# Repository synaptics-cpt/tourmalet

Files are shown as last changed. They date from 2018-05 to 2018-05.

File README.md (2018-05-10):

Synaptics Concept Prototyping Team 

&copy; 2018 Synaptics, Incorporated. All Rights Reserved

# Project Tourmalet - A Portable Multimedia player and Android Design Kit #
last update: May 10, 2018

Contact [Synaptics](mailto:tourmalet@synaptics.com)

The files in this repository, except where otherwise noted, are licensed under the Apache License, Version 2.0 (the "License"); you may not use these files except in compliance with the License. You may obtain a copy of the License at http://www.apache.org/licenses/LICENSE-2.0

*Legal Disclaimer: The information contained in this repository ("Tourmalet") is provided "as is," and Synaptics makes no warranties, express, implied, statutory, or otherwise, regarding Tourmalet or any related documentation.  Synaptics disclaims all liability of any kind in connection with Tourmalet and related documentation and specifically disclaims any implied warranties of noninfringement, title, merchantability, or fitness for a particular purpose, or arising from a course of dealing or usage of trade.* 

----------

Welcome to the Project Tourmalet Repository.  This should be the first document that you read about this project.  Here, you will find a high level description of the purpose, intent and vision of this project.  You will also find a roadmap of the other files and documents that are included in this repository.  

TL;DR: READ THIS DOCUMENT FIRST.  It will save you time.

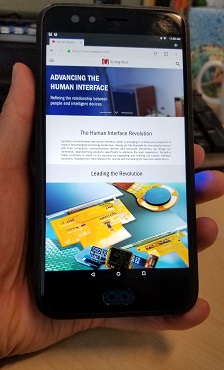
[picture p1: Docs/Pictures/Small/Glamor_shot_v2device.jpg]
Glamour Photo of Tourmalet Device Glamor photo of Tourmalet


## What is Project Tourmalet?  Why? ##

- A build kit for a handheld device and touchscreen development kit
	- Out-of-the-box experience (well, once assembled) as a handheld Android device – impress your friends with a hand-built Android device that can serve as a wireless communicator, music player, social media portal, etc.
	- Usable as a touchscreen development kit to enable touchscreen UI and GPIO access for other projects
- For the recreational hobbyist, a kit to build an Android handheld!
	- Build-it-yourself, battery operated handheld device kit with step-by-step instructions.  HW and SW binary image fully tested to work (so long as you follow our instructions).
	- Fully working high-end media player: FHD touchscreen, USB ports, rechargeable battery, WiFi and Bluetooth. FHD display comparable to any commercially available media player or low-end cell phone.
	- Runs Android OS, can install Amazon AppStore and run apps like Facebook, YouTube, FireFox. Infinitely customizable/personalizeable as HW and SW is "open sourced".
- For the advanced hobbyist, an extensible HD touchscreen development kit
	- Synaptics TDDI FHD touchscreen display easily outperforms other touchscreens currently available to hobbyists.
	- "Simplify" hobbyist touch-screen design-in experience for projects requiring touchscreen
		- Pre-defined touchscreen with HD display, sample source, GUI builder SW
		- NO SENSOR TUNING.  Touchscreen reports multi-finger touch "out-of-the-box" 
	- "...better than ripping apart a production handset just to get to the touchscreen"
		- I/O ports accessible to wire-in additional HW
		- Entire device documentation available (HW schematics, board files, casing design, SW source, etc.)

Project Tourmalet started as an internal Synaptics project to help our engineers learn more about the Synaptics Touch-Display Driver Integration (TDDI) technology.  This pioneering technology enables high-performance in-cell touchscreen display technology by co-locating the capacitive touch sensing circuits directly in the same silicon as the display driver circuits.  

As a service to the Maker community, Synaptics has now made this advanced display technology available on a widely available, hobbyist platform (the Qualcomm Dragonboard 410c).  Furthermore, because we ourselves like to make usable platforms, we have released all the instructions and documentation to enable the Maker community to build a complete stand-alone Android device using the Synaptics TDDI FHD touchscreen. 

The original intent for the Tourmalet kit was to create a design kit that was straightforward enough that even a recreational hobbyist could assemble it him/herself, just like putting together a Lego design or an Ikea furniture.  Accordingly, emphasis was placed on making the mechanical design and assembly simple and robust, at the slight penalty for sleekness and cost.  So yes, the overall design could have been optimized to make the device thinner, but that would have made assembling the device even more challenging.  Additionally, aside from the touchscreen display, we also wanted to make sure most of the components (such as the battery, processor platform, etc.) were easy to source.  We even tested the casing design to be printable using hobbyist-class FDM printers (not just the high-end objet printers).  

That said, we do recognize that the Synaptics-enabled TDDI touchscreen and the main daughterboard and adaptor board that connects the display to the Dragonboard are both not available on the open market.  Full documentation for these two boards are included (in the *Synaptics_Boards* directory) so you could make your own.  However, Synaptics intends on working with suppliers in the Maker community to make these displays and the support components available. Contact [Synaptics](mailto:tourmalet@synaptics.com?subject=Tourmalet%20availability%20request) for further information.  

## How do I get started? ##
Now that we've captured your interest in building your own Android device, the next step is to work through the rest of the collateral and documentation in this repository (in the *Docs* to build your own Tourmalet device. A quick tour (in approximate order of how you will build your device):

1. [The Bill of Materials](Docs/BOM.md). This document contains all the hardware components needed to assemble the device.  Links to where our team sourced the component are also provided.
2. [The Assembly Instructions](Docs/Assembly.md).  Once you have gathered all your components, here are the step-by-step instructions on how to assemble the device.
3. [Installing Android](Docs/InstallingAndroid.md). Once you have your device completely assembled, this document shows you how to install the software binary image onto your device.  In this repository, we have already included a working binary (assuming you used the same exact hardware we specified in the BOM), so you can just install this binary onto your device.  Otherwise, you can try your hand at building your own binary with our [Building Android](Docs/BuildingAndroid.md) guide (see below).
4. [User Guide](Docs/UserGuide.md). What to know about the device and how to use it. Includes a basic spec sheet for the device.
5. [Developer Guide](Docs/DeveloperGuide.md). How to access Tourmalet's hardware in Android apps (or from your PC).
6. *For Advanced Hobbyists only:* [Building Android](Docs/BuildingAndroid.md).  Read this if you are interested in compiling your own Android binary for Tourmalet.  For most hobbyists, you can just use the pre-built binary we have included in the repository.  Building a new binary is really only necessary if you want to see how an Android binary is built (the included scripts and patches are what we used to build the binary in the repository), or if you want to modify our scripts/patches because you want to modify our hardware.  
7. No project would be complete without an [Errata](Docs/Errata.md).  Sadly, not everything is working and there are some things that don't behave as ideally as they should.  Perhaps, you can think of this document as a suggestion list for future projects!

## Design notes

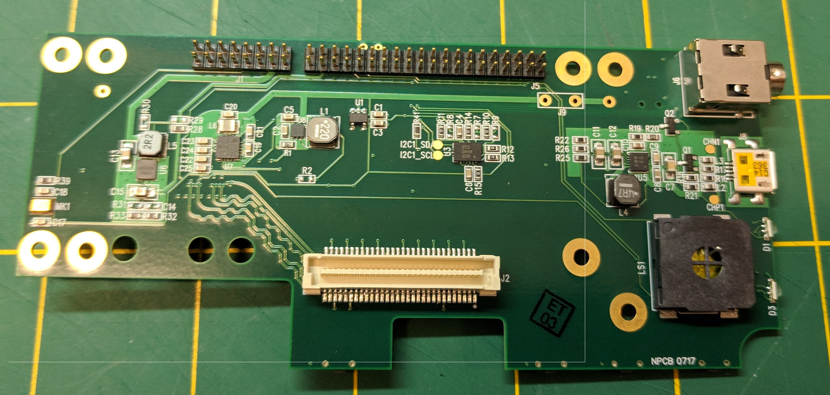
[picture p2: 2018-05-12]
Docs/Pictures/Full_size/daughter_board.jpg

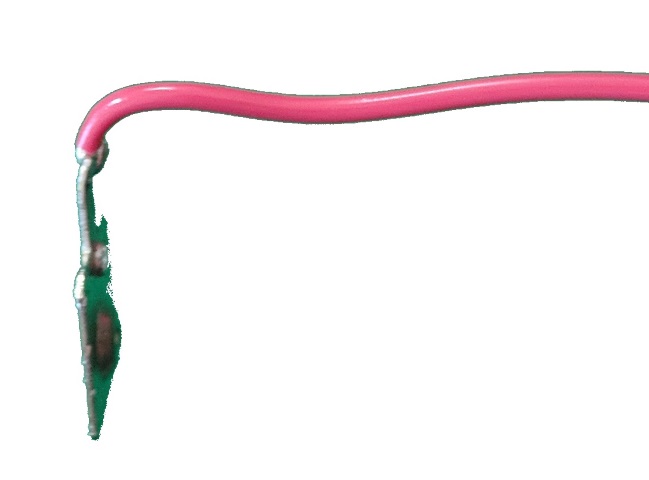
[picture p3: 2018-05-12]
Docs/Pictures/Small/wired_contact.jpg

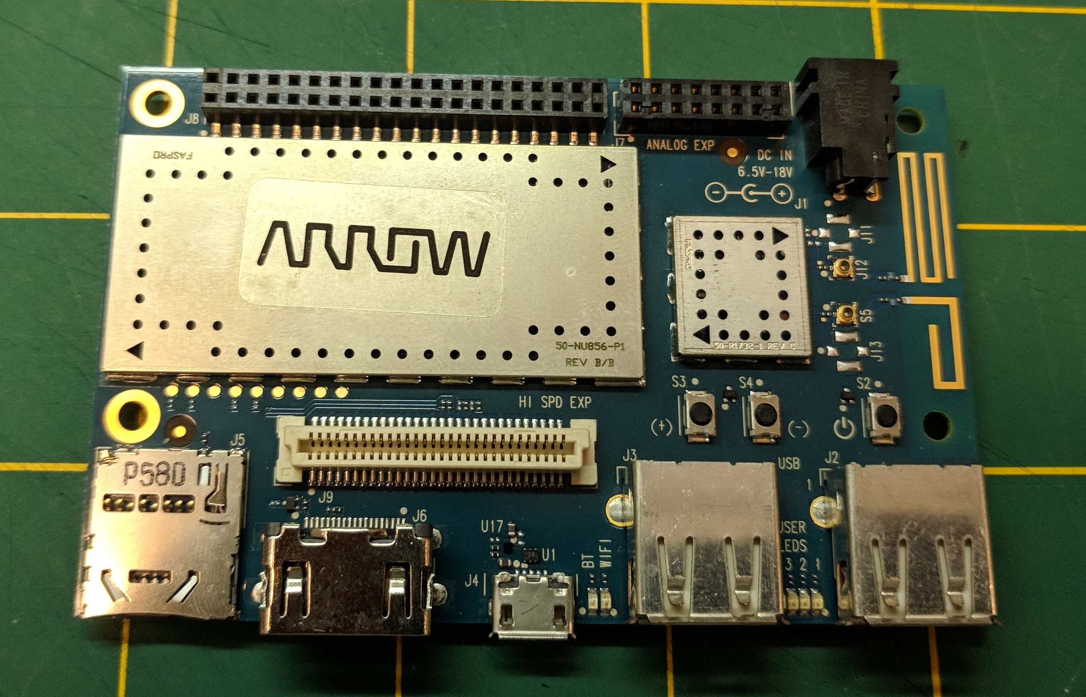
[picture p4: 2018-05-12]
Docs/Pictures/Full_size/dragonboard.jpg

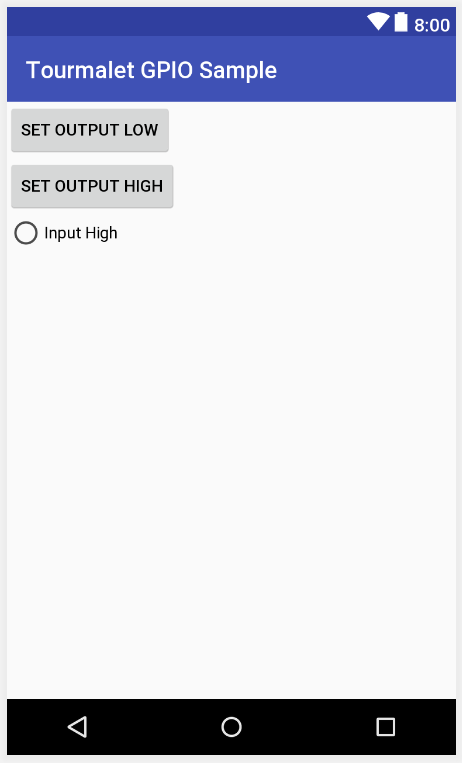
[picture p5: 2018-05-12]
Docs/Pictures/Full_size/Tourmalet_GPIO_Sample.png

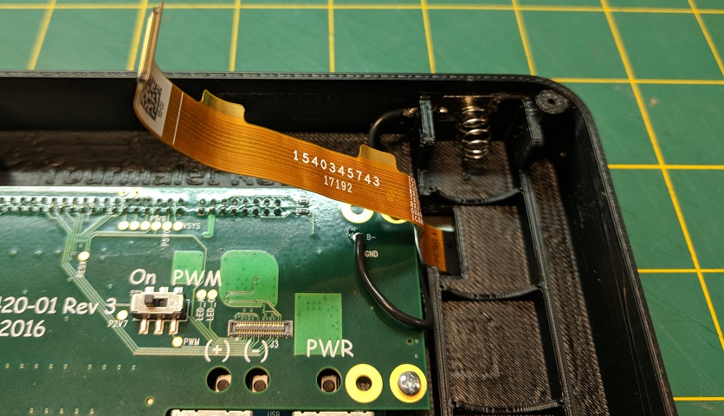
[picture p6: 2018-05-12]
Docs/Pictures/Small/negative_wire.jpg

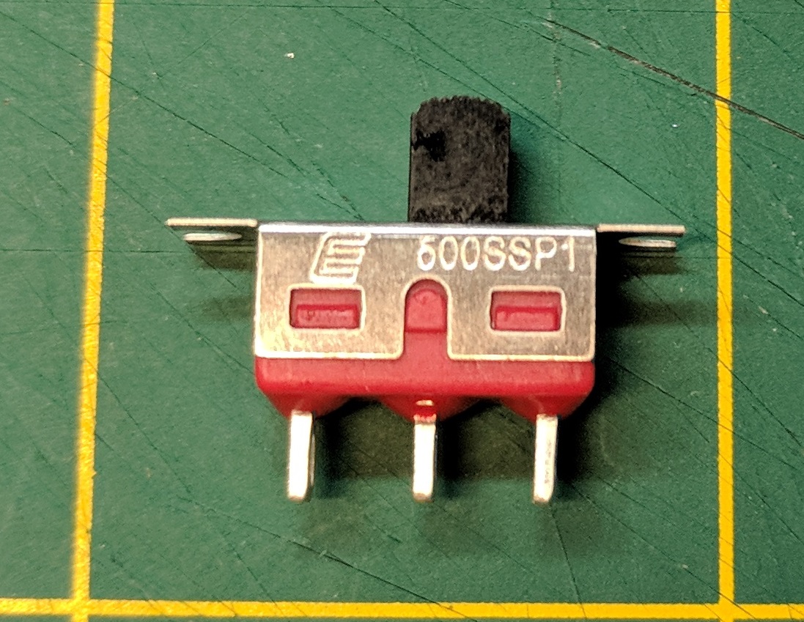
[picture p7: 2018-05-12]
Docs/Pictures/Full_size/switch.jpg

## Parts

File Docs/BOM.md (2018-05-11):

Synaptics Concept Prototyping Team 

&copy; 2018 Synaptics, Incorporated. All Rights Reserved
# Tourmalet Hardware Bill Of Materials

last update: May 10, 2018

Contact [Synaptics](mailto:tourmalet@synaptics.com)

This document tells you what all the parts are, where to get them, and what they look like.

## Parts list, and where to get them
| Item | Component (click link for source) | Quantity | Comments |
|---|---|---:|---|
| [3D Housing](#3d-printed-housing) | 3D case (Rev03a): [top](../Casing/Rev03a_shell_top.STL) and [bottom](../Casing/Rev03a_shell_bottom.STL)- or [one piece](../Casing/Rev03a_one_piece_shell.STL) | 1 | |
| [3D printed buttons](#3d-printed-buttons) | [3D printed buttons](../Casing/Rev03a_buttons.STL) | 1 | |
| [Processor platform](#dragonboard) | [Qualcomm Dragonboard 410c](https://www.arrow.com/en/products/dragonboard410c/arrow-development-tools) | 1 | May need to order from eBay |
| Daughterboard connector | 16-pin, 2 mm double row header, Digikey [609-2660-ND](https://www.digikey.com/product-detail/en/amphenol-fci/63453-116LF/609-2660-ND ) | 1 | |
| [Daughterboard](#daughter-board) | Synaptics internal part 950-000420-01 | 1 | Contact [Synaptics](mailto:tourmalet@synaptics.com) |
| [Battery contacts](#battery-contacts) | Negative: Digikey [36-5201-ND](https://www.digikey.com/product-detail/en/keystone-electronics/5201/36-5201-ND) | 1 | |
| | Positive: Digikey [36-5223-ND](https://www.digikey.com/product-detail/en/keystone-electronics/5223/36-5223-ND ) | 1 | |
| [Touchscreen](#touchscreen) | Tianma TL055VVMS15-00 (Synaptics TDDI) | 1 | Contact [Synaptics](mailto:tourmalet@synaptics.com) |
| [LCD Adaptor Board](#lcd-adaptor-board) | Synaptics internal part 950-000550-01 | 1 | Contact [Synaptics](mailto:tourmalet@synaptics.com) |
| [Power Switch](#power-switch) | SPDT switch: Digikey [EG2476-ND](https://www.digikey.com/product-detail/en/e-switch/EG2476-ND) | 1 | |
| [Battery](#battery) | [18650 Li-Ion battery](https://www.ebay.com/gds/18650-Battery-Buying-Guide-/10000000177628747/g.html) | 1 | Various sources; see ebay buying guide |
| [Themistor](#battery) | Digikey [490-8601-ND](https://www.digikey.com/product-detail/en/murata-electronics-north-america/NXRT15XH103FA1B030/490-8601-ND/3788625) | 1 | |
| Screws | M2 x 5 pan head | 12 | |
| | M2 x 3 flat head | 2 | |
| Misc. Wire | 22 or 24 gauge in various colors (red, black, etc.) | TBD | |
| [Pressure Sensitive Adhesive](#pressure-sensitive-adhesive) | 3M VHB 5909, 486MP, or similar | TBD | |

## Further explanation of the parts

### 3D Printed Housing
Part files are available as two pieces- [top](../Casing/Rev03a_shell_top.STL) and [bottom](../Casing/Rev03a_shell_bottom.STL)- or [one](../Casing/Rev03a_one_piece_shell.STL). The one-piece housing may be more difficult to print correctly and only saves 1mm in height.

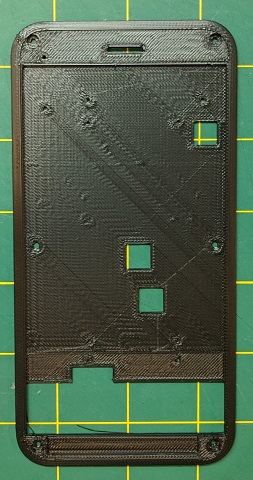
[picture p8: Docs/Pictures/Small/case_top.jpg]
Case top Casing top
 
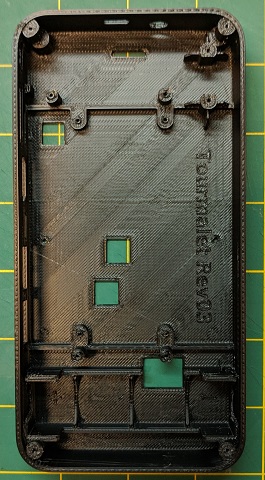
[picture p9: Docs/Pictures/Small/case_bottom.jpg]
Case bottom Casing bottom


### 3D Printed Buttons
Same [part](../Casing/Rev03a_buttons.STL) is used for both two-piece and single piece shell.

### DragonBoard
We are using the Dragonboard 410c.  This SBC is available from various online resellers. We got ours from [Arrow](https://www.arrow.com/en/products/dragonboard410c/arrow-development-tools), though you may need to check around as the 410c was released in 2016, so it's getting a bit old.
We will flash our build image after assembly, but make sure the DIP switches are all set to OFF.

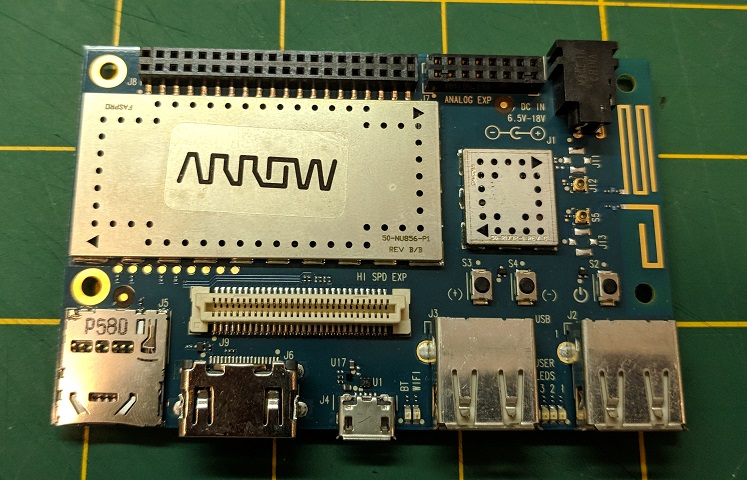
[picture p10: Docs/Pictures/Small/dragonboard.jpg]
Dragonboard Dragonboard 410c from Arrow


### Daughter Board
This Synaptics-design daughterboard (950-000420-01) contains a MIPI DSI connector (via an [adaptor board](#lcd-adaptor-board)), 3.3V display power, drive current for LED display backlight (and switch), speaker, battery charging, headphone jack, expansion connector, power for USB ports, and 9-axis sensor (magnetometer, accelerometer and gyroscope).  

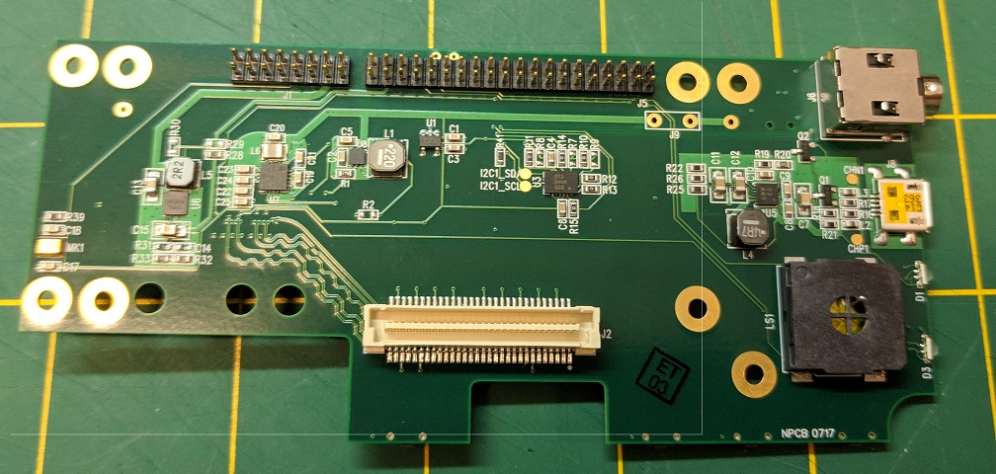
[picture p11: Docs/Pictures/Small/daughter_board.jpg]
daughter board Don't try building this by yourself!


All information needed to build this board (BOM, Schematic, PCB artwork) is contained in the *Synaptics_Boards* directory. However, we are assuming that you have an assembled daughterboard already, as the sourcing, PCB fab, assembly, and testing of this board is a rather advanced project in itself.  Contact [Synaptics](mailto:tourmalet@synaptics.com) for further information about sources for this board.

### Battery Contacts
Digikey part numbers available in the table above.

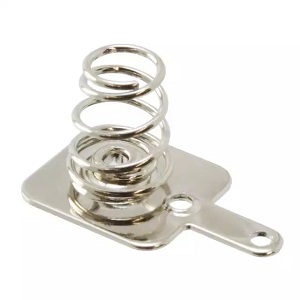
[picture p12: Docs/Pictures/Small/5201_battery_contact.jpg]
Negative battery contact
 
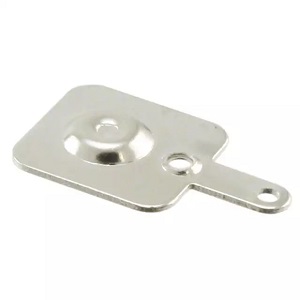
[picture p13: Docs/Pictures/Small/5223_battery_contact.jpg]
Positive battery contact


### Touchscreen
This is a Tianma TL055VVMS15-00 in-cell touchscreen display with an integrated cover lens.  It is a 5.46" FHD (1920 x 1080) touchscreen module, with integrated cover lens.  This touchscreen module features a Synaptics TD4322 touch-display driver integration (TDDI) chipset to provide high-performance in-cell capacitive multitouch.  Communication with the dragonboard is done via a MIPI DSI connection.  

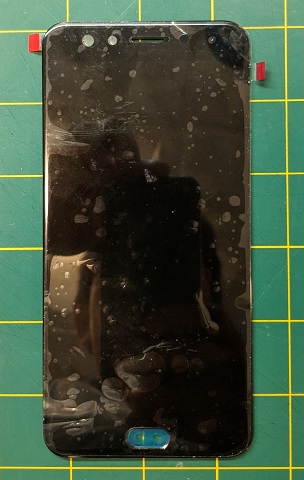
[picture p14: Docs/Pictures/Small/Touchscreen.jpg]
Touchscreen


In order to get the current version of Tourmalet to work with the supplied software binary image, it is critical that this exact touchscreen display be used.  No other display will work with this software binary, as the display configuration parameters in the binary are specifically tuned to this display. 

Contact [Synaptics](mailto:tourmalet@synaptics.com) for further information about sourcing this display.

### LCD Adaptor Board
Currently, the daughterboard (520-000420-01) with all the DragonBoard interface connectors (mezzanine connector, analog hconnector, and high speed digital signals) was designed for an LCD with a different pinout, even though it has the same connector as the Tianma LCD used in this case. This LCD adapter board (520-000550-01) is needed to work with the Tianma LCD. A future iteration of the daughterboard might correct the LCD pinout to eliminate this adapter board.  

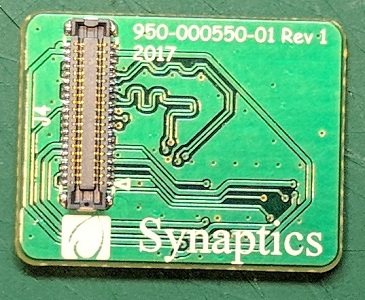
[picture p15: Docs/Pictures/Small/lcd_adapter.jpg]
LCD adapter board LCD adaptor board for daughterboard


All information about this board (BOM, schematic, PCB artwork) can be found in the *Synaptics_Boards* directory, though sourcing the connector may be an issue. Contact [Synaptics](mailto:tourmalet@synaptics.com) for further information about sources for this board.

### Power Switch
Power switch

Because we have not been successful at controlling the DragonBoard's PMIC, it is currently not possible to shut down the processor via software. Attempting to do so only works until the watchdog timer turns the Dragonboard back on again.  Accordingly, we have included a power switch, so you do not have to remove the battery whenever you want to turn off your Tourmalet device. Regular standby does work to shut off the LCD (and possibly put the processor in a lower power state?), but will still eventually drain the battery.
The power switch can be bypassed and not even used by putting a jumper (or zero ohm resistor) in part R40 on the daughter board.

### Battery
The battery used here is a relatively standard size rechargeable Lithium Ion cell. There is much more information available about these batteries than we can relay here, thus the link to a quick primer on eBay, above.

Due to the battery contacts, we recommend the use of button top (instead of flat top) batteries. We also recommend the use of protected cells for general safety. A protected 18650 battery is one that has a circuit on it to prevent electrical damage to the cell due to such factors as over charging, over discharging, short circuits, etc. 

Being a Lithium Ion battery, there are certain precautions one should follow when using it to reduce the risk of fire. We attempt to prevent charging problems by using a lithium ion specific charging ASIC, and we charge the battery at a moderate current. This means that the battery does not charge as fast as it could, but it also allows for different capacity batteries and also extends their service life.

We also provide contacts for the thermistor that the charging ASIC has provisions for. This thermistor is placed next to the battery so that charging circuit can reduce the charging current if the battery is getting too hot. Unfortunately, on the most recent board (as of April 2018), these contact are far from the actual battery itself, so the thermistor needs to have additional wires soldered to it so that it can properly be placed by the battery.

### Pressure Sensitive Adhesive
This adhesive needs to be able to stick well to both the smooth glass of the touchscreen, and the rough surface of the 3D printed case. The 3M VHB is often used for attaching glass to plastic. For FFF 3D printed materials, the adhesive should be at least 0.2mm thick. The VHB 5909 used here is 0.3mm. We have done no rigorous testing to determine the optimal adhseive - we simply had this particular adhesive available, and it seems to work well enough to keep the touchscreen attached to the plastic case.

If the surface texture of the plastic case is smooth - for example, if the case is made from a smooth photoresin, or the surface has been smoothed with filler such as epoxy or Bondo- then a 3M 200 series adhesive, such as 468MP, might be acceptable.

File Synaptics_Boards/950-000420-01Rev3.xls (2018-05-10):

SCH,DRAGONBOARD 410C TO DISPLAY ADAPTOR Revised: Thursday, April 26, 2018
SC950-000420-01 Revision: 3
Item | Quantity | Reference | Part | Decal | DigiKey
1 | 5 | C1,C5,C6,C9,C19 | 2.2uF | 0603 | 587-1430-1-ND
2 | 1 | C2 | 1.0uF | 0603 | 587-4958-1-ND
3 | 8 | C3,C4,C8,C16,C17,C18,C24,C25 | 0.1uF | 0603 | 490-6049-1-ND
4 | 2 | C7,C13 | 10uF | 0805 | 490-5523-1-ND
5 | 1 | C10 | 0.22uF | 0603 | 490-3290-1-ND
6 | 3 | C11,C12,C15 | 22uF | 0805 | 490-10511-1-ND
7 | 4 | C20,C21,C22,C23 | 4.7uF | 0603 | 587-3416-1-ND
8 | 2 | D1,D3 | 598-8510 | 598-8510 | 350-2072-1-ND
9 | 1 | D2 | BAT54C | SOT23 | BAT54C-FDICT-ND
10 | 1 | J1 | CON16A | 57102-xxx-08 | 609-2597-ND
11 | 1 | J2 | CON60 | 61083-06xx0x | 609-1677-1-ND
12 | 1 | J3 | CON40A | WP7B-S040VAX_ALT | 670-2806-1-ND
13 | 1 | J5 | CON40A | 57102-XXX-20 | 609-2589-ND
14 | 1 | J6 | SJ-435107RS | SJ-435107RS | CP-435107RS-ND
15 | 1 | J8 | uUSB | MOLEX47642-0001 | WM1398CT-ND
16 | 1 | LS1 | SPEAKER | SMS-1508 | 668-1260-1-ND
17 | 1 | L1 | 22uH | NRS5030 | 587-2411-1-ND
18 | 2 | L2,L3 | F-BEAD | 603 | 490-5222-1-ND
19 | 1 | L4 | 4.7uH | NRS5030 | 587-3461-1-ND
20 | 1 | L5 | 2.2uH | ASPI-0418FS | 535-10759-1-ND
21 | 1 | L6 | 4.7uH | 1008 | 490-10577-1-ND
22 | 1 | MK1 | SPA2410LR5H-B | SPA2410 | 423-1161-1-ND
23 | 4 | VOLUP,VOLDN,RST,PWR | SW SPST | EVQ9P701P | P19095CT-ND
24 | 4 | Q1,Q2,Q3,Q4 | 2N7002 | SOT23 | 2N7002K-7DICT-ND
25 | 1 | R1 | 5.1 | 0603 | P5.1GCT-ND
26 | 2 | R5,R39 | 2k | 0603 | P2.00KHCT-ND
27 | 3 | R6,R33,R34 | 105k | 0603 | P105KHCT-ND
28 | 6 | R10,R11,R12,R13,R14,R15 | 0 | 0603 | P0.0GCT-ND
29 | 5 | R16,R18,R22,R28,R41 | 47k | 0603 | P47.0KHCT-ND
30 | 1 | R17 | 470k | 0603 | P470KHCT-ND
31 | 1 | R19 | 27k | 0603 | P27.0KHCT-ND
32 | 1 | R20 | 22k | 0603 | P22.0KHCT-ND
33 | 1 | R21 | 100 | 0603 | P100HCT-ND
34 | 2 | R23,R38 | 270 | 0603 | P270HCT-ND
35 | 2 | R24,R37 | 330 | 0603 | P330HCT-ND
36 | 2 | R25,R36 | 12.4k | 0603 | P12.4KHCT-ND
37 | 1 | R26 | 53.6k | 0603 | P53.6KHCT-ND
38 | 1 | R27 | 10k@25°C | NXRT15 | 490-8601-ND
39 | 1 | R32 | 768k | 0603 | P768KHCT-ND
40 | 1 | R35 | 1.5k | 0603 | P1.50KHCT-ND
41 | 1 | SW1 | SW SPDT | JS202011SCQN | 401-2002-1-ND
42 | 1 | SW5 | SW DPDT | AYZ0202 | 401-2013-1-ND
43 | 1 | U1 | TC1014 | SOT23-5 | TC10142.7VCT713CT-ND
44 | 1 | U3 | BMX055 | BMX055 | 262-BMX055
45 | 1 | U4 | ADCMP670 | SOT23-6 | ADCMP670-1YUJZ-RL7CT-ND
46 | 1 | U5 | AAT3620 | TDFN14_040 | 863-1509-1-ND
47 | 1 | U6 | PAM2401_DFN | DFN12_045 | PAM2401YPADJDICT-ND
48 | 1 | U7 | BD83854MUV | QFN20_050 | BD83854MUV-E2CT-ND
49 | 1 | U8 | AL3050 | DFN6_065 | AL3050FDC-7DICT-ND

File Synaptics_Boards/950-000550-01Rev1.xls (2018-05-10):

SCH,Tourmalet Display adaptor Revised: Wednesday, September 06, 2017
SC950-000550-01 Revision: 1
Item | Quantity | Reference | Part | Decal | DigiKey
1 | 1 | J3 | 950-000420-01Rev1 | WP7B-P040VAX_SEQ_MIR | 670-2813-1-ND
2 | 1 | J4 | Display | AXE540xxx_ALT | 255-5433-ND

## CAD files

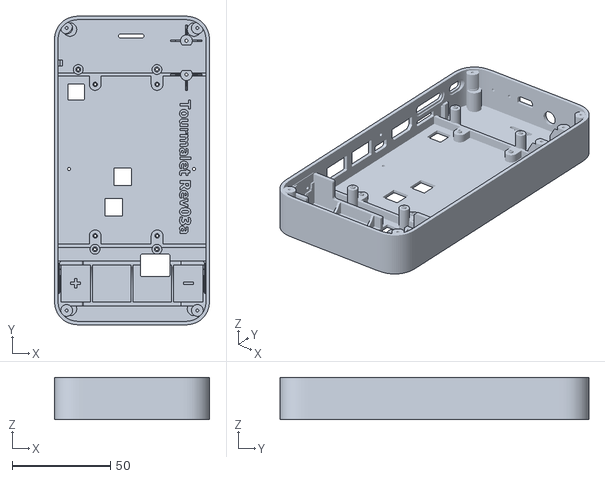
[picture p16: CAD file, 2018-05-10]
Casing/Rev03a_shell_bottom.STL
79.0 x 157.1 x 21.5

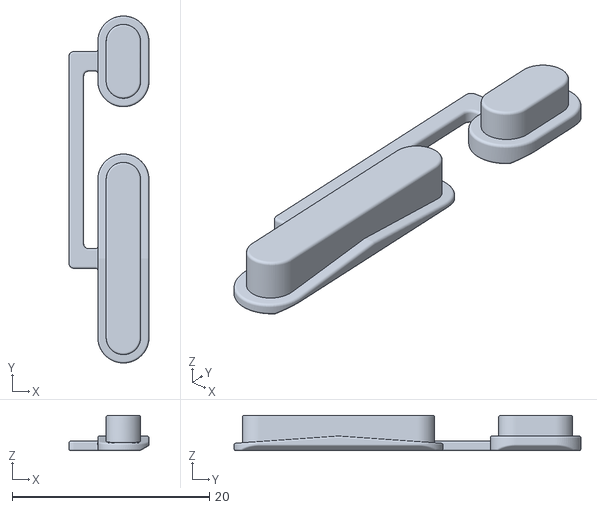
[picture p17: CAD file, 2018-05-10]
Casing/Rev03a_buttons.STL
8.12 x 35.2 x 3.60

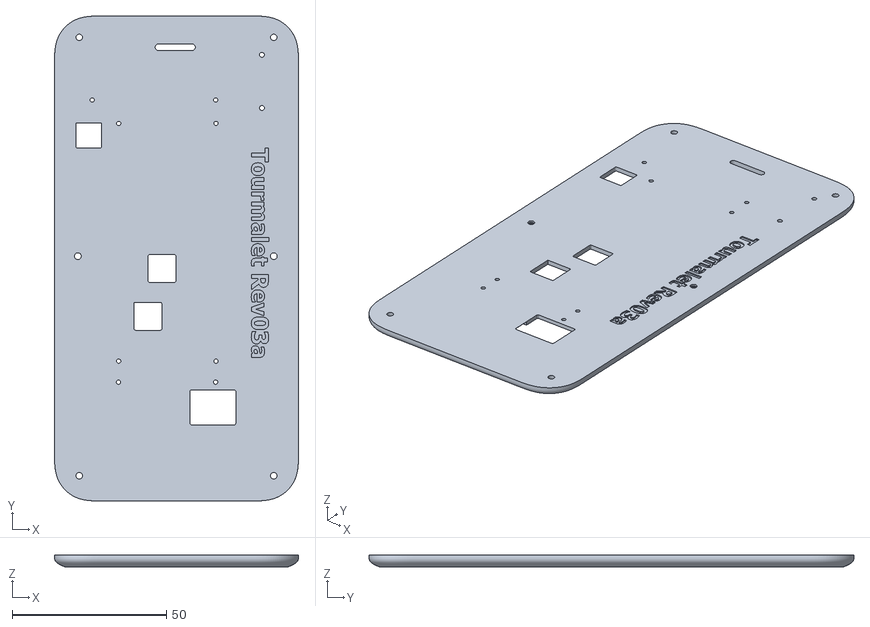
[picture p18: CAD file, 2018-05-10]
Casing/Rev03a_shell_top.STL
79.0 x 157.1 x 3.74

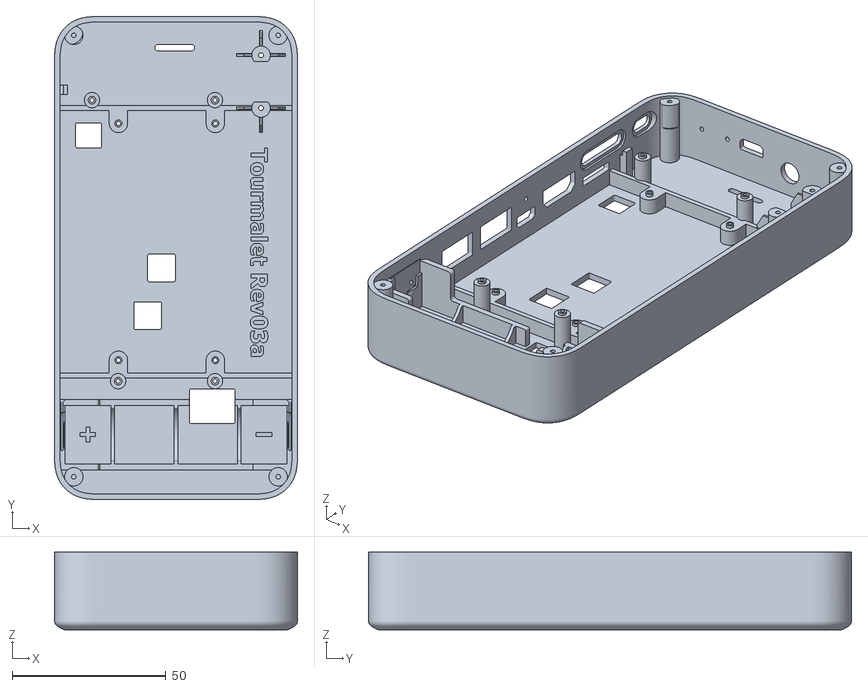
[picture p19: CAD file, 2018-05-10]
Casing/Rev03a_one_piece_shell.STL
79.0 x 157.1 x 25.2

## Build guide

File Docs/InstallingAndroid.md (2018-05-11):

Synaptics Concept Prototyping Team 

&copy; 2018 Synaptics, Incorporated. All Rights Reserved

# Installing Android on Tourmalet #

last update: May 10, 2018

Contact [Synaptics](mailto:tourmalet@synaptics.com)

- Install Android SDK from https://developer.android.com/studio/ or just the Platform Tools (smaller download/installation) from https://developer.android.com/studio/releases/platform-tools or, on Ubuntu Linux, fastboot as below:
```{r, engine=sh}
sudo add-apt-repository ppa:nilarimogard/webupd8
sudo apt-get update
sudo apt-get install android-tools-fastboot
```

- If you are using Ubuntu Linux, Install udev rules so that adb and fastboot will work without root permissions (or remember to use su or sudo to run adb and fastboot):

```{r, engine=sh}
git clone https://github.com/snowdream/51-android
sudo ln -s `pwd`/51-android/51-android.rules /etc/udev/rules.d/
sudo udevadm control --reload-rules
```
- Make sure the directory containing fastboot is in your `PATH` environment variable.

- Connect your Tourmalet device to your PC in fastboot mode:

	1. Unplug the device and make sure that the device is off
	2. Put in a charged battery (or plug device into charger via the top USB micro port).
	3. With a paperclip or other thin stick, press the *dragonboard's* volume down button (accessed via the middle hole in the daughterboard, located between the USB A ports) and then turn on power switch:

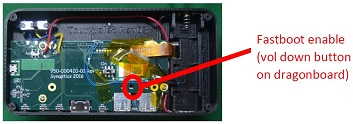
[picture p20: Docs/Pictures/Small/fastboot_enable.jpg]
fastboot_enable Push in this button to enable fastboot
	

	4. Once you switch on the power, you can let go of the button.  Now wait about 20 seconds and then plug the device into your PC via the side USB micro port.
	5. Check to make sure your device is recognized with the `fastboot devices -l` command.
	6. For additional help, you can also refer to the [96boards fastboot help page](https://www.96boards.org/documentation/consumer/dragonboard410c/installation/linux-fastboot.md.html), especially steps 1 and 2.

- Extract [fastboot-images.zip](https://github.com/synaptics-cpt/tourmalet/releases/download/v1.0.0/fastboot-images.zip) (`unzip fastboot-images.zip`).  

- On Windows, run `flash-all.bat`; on other platforms, `./flash-all.sh`.

- If you built your own image from source (using [Building Android](BuildingAndroid.md)), you will need to run these commands (that is, building your own "flash-all" script):

```{r, engine=sh}
for i in boot system userdata persist recovery; do fastboot flash $i APQ8016_420C_LA.BR.1.2.4-01810-8x16.0_5.1.1_Lollipop_P2/out/target/product/msm8916_64/$i.img; done
fastboot reboot
```

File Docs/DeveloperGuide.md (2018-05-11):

Synaptics Concept Prototyping Team 

&copy; 2018 Synaptics, Incorporated. All Rights Reserved

# Developer Guide #

last update, May 10, 2018

Contact [Synaptics](mailto:tourmalet@synaptics.com)

Writing Android apps to use Tourmalet hardware features such as GPIOs, UART, and buses requires some understanding of three layers: [Electical](#electrical) connections & pinout, [sysfs](#sysfs) interface for Linux hardware access, and using [libsuperuser](#libsuperuser) to get a privileged command shell from Android.

## Electrical ##

The DragonBoard 410c provides access to many I/O lines on the 40 pin low speed header. Some of these are used by the DragonBoard or Tourmalet expansion board and should generally not be used for further expansion, as this may cause hardware contention issues and unexpected behavior.

| Pin number | Signal name  | GPIO number | comment | | Pin number | Signal name  | GPIO number | comment |
| ---: | :---: | ---: | :--- | - | ---: | :---: | ---: | :--- |
| 1 | GND | | logic level low  | | 2 | GND | | |
| 3 | UART0_CTS | 904 | | | 4 | Power button | | |
| 5 | UART0_TX | 902 | | | 6 | Reset button | | |
| 7 | UART0_RX | 903 | | | 8 | SPI0_CLK | 921 | accelerometer |
| 9 | UART0_RTS | 905 | | | 10 | SPI0_MISO | 919 | accelerometer |
| 11 | UART1_TX | 906 | | | 12 | SPI0_CS_N | 920 | accelerometer |
| 13 | UART1_RX | 907 | | | 14 | SPI0_MOSI | 918 | accelerometer |
| 15 | I2C0_SCL | 909 | touch at 0x20 | | 16 | Reserved | | |
| 17 | I2C0_SDA | 908 | touch at 0x20 | | 18 | Reserved | | |
| 19 | I2C1_SCL | 925 | sensors | | 20 | Reserved | | |
| 21 | I2C1_SDA | 924 | sensors | | 22 | Reserved | | |
| 23 | GPIO_36 | 938 | 5V enable | | 24 | GPIO_12 | 914 | |
| 25 | GPIO_13 | 915 | touch ATTN | | 26 | GPIO_69 | 971 | |
| 27 | GPIO_115 | 1017 | gyro ATTN | | 28 | Reserved | | compass ATTN |
| 29 | GPIO_24 | 926 | input only | | 30 | GPIO_25 | 927 | |
| 31 | GPIO_35 | 937 | | | 32 | GPIO_34 | 936 | volume up |
| 33 | GPIO_28 | 930 | | | 34 | GPIO_33 | 935 | volume down |
| 35 | 1.8V PWR | | logic level high | | 36 | SYS DC IN | | |
| 37 | 5.0V PWR | | | | 38 | SYS DC IN | | |
| 39 | GND | | logic level low  | | 40 | GND | | |

### Notes: ###

- Any GND signal (pin 1, 2, 39, or 40) can be used as a reference for logic level low ("false" or '0"); 1.8V can be used as a reference for logic level high ("true" or "1").
- Any input connected to a GPIO (e.g. switches, buttons, etc.) will require a pull-up resistor.  We recommend a 4.7k&Omega; resistor.
- I2C0 (pins 15 & 17) has Synaptics Touch at address 0x20, Gyroscope and accelerometer at 0x68, ambient light and proximity sensor at 0x39, and compass at 0x0c; any other address should be available for use.
- I2C1 (pins 19 & 21) has the DSI to HDMI video converter at address 0x39; any other address should be available for use.
- GPIO_36 (pin 23) controls the 5V power supply on pin 37.
- SPI0 is in use by an accelerometer.
- GPIO_34 (pin 32) and GPIO_33 (pin 34) are the volume buttons on the side of the Tourmalet case/board. They are configured as keycodes 116 and 117.

## sysfs ##

The Linux kernel provides a hardware interface within the filesystem. Many devices, including GPIOs, can be accessed by reading and writing files under the `/sys` directory (exported by a kernel subsystem called sysfs).

### sysfs GPIOs ###

General Purpose Input/Outputs (GPIOs) can be accessed from `/sys/class/gpio/`. Access generally requires a root shell.

```{r, engine=sh}
adb root
adb shell
```

To use a particular GPIO, first write its number to `/sys/class/gpio/export`

```{r, engine=sh}
echo 902 > /sys/class/gpio/export
```

This will create a directory `/sys/class/gpio/gpio<number>`, in this case `/sys/class/gpio/gpio902`, containing several files to access the GPIO.
To use the GPIO as input or output, write `in` or `out` to `/sys/class/gpio/gpio<number>/direction`.

```{r, engine=sh}
echo in > /sys/class/gpio/gpio902/direction
```

To get or set the logic level of the pin (1 for high, 1.8V, 0 for low, 0V), read or write `/sys/class/gpio/gpio<number>/value`

```{r, engine=sh}
cat /sys/class/gpio/gpio902/value
```

For more information, see https://www.kernel.org/doc/Documentation/gpio/sysfs.txt.

## libsuperuser ##

Android apps can get a root shell using [libsuperuser](https://github.com/Chainfire/libsuperuser) and a permissive `su` binary such as [SuperSU](http://www.supersu.com/). Although libsuperuser provides several ways to use a root shell, the simplest and most commonly used is likely

```{r, engine=java}
List<String> Shell.SU.run(String command);
```

This can be called with the shell commands above to access GPIOs, for example

```{r, engine=java}
Shell.SU.run("echo 902 > /sys/class/gpio/export");
Shell.SU.run("echo in > /sys/class/gpio/gpio902/direction");
final String value = Shell.SU.run("cat /sys/class/gpio902/value");
```

[Tourmalet GPIO Sample](../Software/TourmaletGpioSample.zip) is an Android app that exports pin 5 as output, with buttons to set its logic level, and exports pin 7 as input, with a radio button indicating its value. A quick test is to click the buttons with and without pins 5 and 7 shorted together.

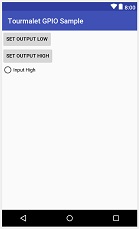
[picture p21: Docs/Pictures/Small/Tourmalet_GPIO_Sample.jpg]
Sample GPIO Sample GPIO test App


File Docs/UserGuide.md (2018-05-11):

Synaptics Concept Prototyping Team 

&copy; 2018 Synaptics, Incorporated. All Rights Reserved

# User Guide #
last update: May 10, 2018

Contact [Synaptics](mailto:tourmalet@synaptics.com)

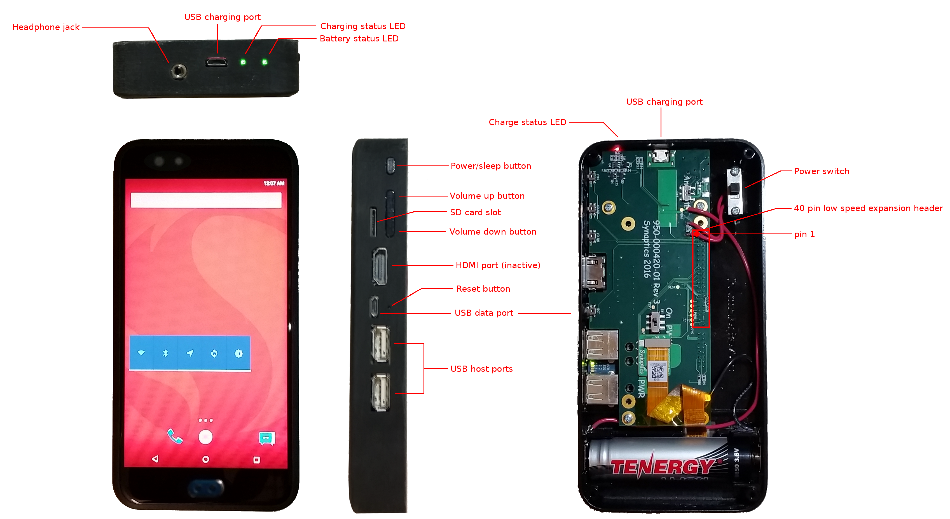
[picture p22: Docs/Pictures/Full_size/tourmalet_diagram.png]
Tourmalet Device Diagram


This user guide will take you through the basics of your Tourmalet device in terms of how to use it as a portable media player.  If you are interested in accessing Tourmalet's GPIO's and other hardware, refer to the [Developer Guide](DeveloperGuide.md). This guide assumes that you already have an [assembled device](Assembly.md) with the appropriate [software image installed](InstallingAndroid.md).  

Tourmalet runs the Lollipop version of Android, so you will find Tourmalet fairly similar in software operation to other Lollipop-era Android devices.  Accordingly, this document assumes familiarity with Android usage, and will only cover Tourmalet-specific issues. For more usage details about Lollipop Android, check out [Google's Lollipop User Guide](https://ss7.vzw.com/is/content/VerizonWireless/Devices/Android-Specific-Images/User%20Manual/android-5-lollipop-ug.pdf).

## Powering on (and off) Device
Make sure you have a charged battery inserted with the correct polarity.  If the battery is not charged, you can use your Tourmalet device to [charge your battery](#battery).

Turn the device on with the power switch on the back. A blue LED on the Dragonboard (between the USB data port and USB host port) may briefly flash.  This is followed by a green LED between the two USB host ports turning on. This LED will eventually turn off after initial booting and will probably be off by the time the display is on. The battery status indicator LED should also be on.  The display will remain dark for about 30 seconds before a splash screen appears. The splash screen will then be replaced by the Android home screen or lock screen.  If the display turns off after you see the splash screen, try pressing the power/sleep button, as the device may have already decided to turn off the display to save power.  If you see the Android lock screen (left image; the time is prominently displayed with a small lock icon at the bottom middle of the display), swipe up to unlock.  You should see the Android home screen (right image), 

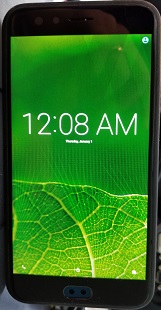
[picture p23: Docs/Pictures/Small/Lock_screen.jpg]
Tourmalet lock screen Tourmalet's lock screen

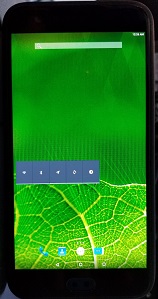
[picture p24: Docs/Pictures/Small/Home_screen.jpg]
Tourmalet home screen Tourmalet's home screen


Now, you are ready to start using your Tourmalet device.  If this is your first time, you will notice that there isn't all that much there.  To add more stuff onto the device, you will first need to turn on [WiFi](#wifi) to get your device onto your wireless network.  Additionally, you will need to side-load a web browser and app store to start loading stuff onto your device.  See the [Setting up Tourmalet](#setting-up-tourmalet-and-installing-apps) section below for some basic instructions on how to set-up your device for the first time.

The power/sleep button works pretty much like the power/sleep button on a cell phone.  That is, a brief press will turn off the display if it is on, and turn on the display if it is off.  A long press on the button will bring up the shutdown menu.  However, shutdown doesn't exactly power off the dragonboard:

To power off the device, you can simply use the power switch at the back of the device again.  This switch directly cuts power to the entire device.  We haven't noticed any particular issues in the software by doing this.  However, we still recommend that you "shutdown" Android first, by a long-press on the power/sleep button (then tap the "power off" button on the screen).  Once the display turns off, use the power switch (otherwise, the device will restart).  Remember, we added a power switch to the device because we were unsuccessful at accessing the Dragonboard's PMIC, so any attempt to power off the device via software will cause the device to ultimately restart (due to the watchdog timer timing out). 

## Setting up Tourmalet and Installing Apps ##

The first time, you start up your device, you will notice that there isn't much to do.  The calculator works, as does the stopwatch.  Other apps such as the phone, music, and videos, don't do much, as there is no cellular chipset or media content to play.  Even if [WiFi](#wifi) is operational, there is no web browser available on the initial image.  

So, the first thing you will likely need to do is install a web browser and an app store app to your device.  This can be done by connecting your Tourmalet to a PC running adb (also known as "side-loading"). Apps in the form of APK files can be installed with `adb install <filename>.apk`. 

Web browsers such as Chrome or [Mozilla](https://download.mozilla.org/?product=fennec-latest&os=android&lang=multi) are easily available as APKs with a quick Internet search. App stores from Amazon, F-Droid, and others are available as APKs.  These app stores will allow installation of additional apps through the interface on the Tourmalet device without the need to continue using adb. A list of popular alternatives to the Google Play store can be found in this [article](https://www.androidpit.com/best-google-play-store-alternative-app-stores).  

To date, we have side-loaded Mozilla, and the Amazon store.  Inside the Amazon store, we were able to download the Facebook app directly onto the Tourmalet device and then install and run Facebook.

**Note**:  Before launching the web browser for the first time, be sure to set the time, date, and time zone on your device (via the *Settings* menu).  Otherwise, you may get connection errors when you launch your web browser, due to timestamp mis-matches.

## WiFi ##

WiFi may take a few minutes to initialize, but once it does should work the same as any Android device. Due to the location and design of the antenna, signal may be weaker than desired. If you are experiencing issues or want a better connection, you can install a [replacement antenna](Assembly.md#wifi-antenna).

Please note that the WiFi upon start-up is disabled, so you need to enable WiFi each time you reboot the system.  We are not sure why the state of the device's WiFi connection is not preserved during shutdown/reboot (unlike Bluetooth).

## Audio ##

Tourmalet has volume up and down buttons on the side of the case (the edge of the daughterboard) in addition to the volume buttons on the DragonBoard (accessible through holes in the daughterboard).

Headphones with or without a microphone can be connected to the 3.5mm jack at the top of the case. Only for headphones with a microphone: next to the power switch is a smaller switch on the daughter board for Android-compatible headsets ("An" position) or iPhone-compatible headsets ("iP" position):  

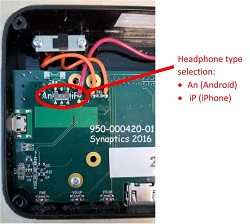
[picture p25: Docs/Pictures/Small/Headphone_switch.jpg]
Headphone Switch Headphone Switch on daughterboard


The position of this switch is irrelevant if your headphone does not have a microphone.

Bluetooth audio devices can also be used.  Just go to the Settings menu in Android and pair your bluetooth audio device.  We have tested this with a pair of Bluetooth speakers.

Finally, there is a speaker built into the Synaptics daughterboard.  As of this build, the speaker does not seem to be enabled.

## USB ##

The Micro-USB port at the top of the case is for charging only. It can charge the battery whether the main power switch is on or off. See [battery](#battery) for more details. 

The Micro-USB port on the DragonBoard can be used for ADB, fastboot, and file transfer.

The two USB A ports can be used to connect devices such as mouse and keyboard.

## Battery ##

The Tourmalet device utilizes a relatively common and plentiful 18650 Li-ion battery.  This battery typically has between 3100 to 3400 mAhr capacity.  The *approximate* state of the battery is shown by the LED furthest from the USB charging port:

|Color | Status |
|---|---|
|Green | Full charge |
|Orange | Not full charge |
|Red | Better think about charging  |

Look, this is a hobbyist project.  Just be happy that we put an LED to give you a rough idea of the state of the battery.  In previous projects that the team worked on, such an LED was not designed in.  You can imagine the stress level during customer demos when we would have no idea how much longer the demo would last before the battery died...

To give you a better idea of battery life, here are some preliminary power consumption measurements:

### Battery Life ###

| Device State | Current draw (mA)  | Operating Time* (Hours) |
|---|---:|---:|
| "Sleep" (i.e. after pushing power/sleep button) | 60 | 57 |
| Sleep + backlight forced on (see [Misc](#backlight-switch)) | 330 | 10 |
| Normal "idle" state (home screen), no WiFi, no BT | 380 | 9 |
| Normal, with BT, no WiFi | 400 | 9 |
| Normal, with WiFi, no BT | 410 | 8 |
| Continuous Streaming Video on YouTube, WiFi, BT on, display always | 670 | 5 |
| Downloading app, WiFi, BT on | 800 | 4 |

\* Operating Time based on 3400 mAh battery

Basically, you can expect about 4 hours of continuous use from a fresh battery.  The default power management in Android shuts off the display after about a minute, so battery life may be much longer when the display is not always on.

**Note:** In some tests, we have seen a device consume about 800 mA in its sleep state, and about 1500 mA (or even more) in normal operation.  We are not sure why this happens, but it seems independent of the software image (we've observed similar results on an alternate, non-Tourmalet Dragonboard image).  As you can imagine, battery life is much shorter when we observed this.  More importantly, the daughterboard and display will feel hot when touched, though otherwise operate normally.  If you encounter this issue, try shutting down the device and letting it cool down before restarting.

### Charger LED status ###

Since we were unable to get the Dragonboard on-board charger to work, we added our own on the daughterboard.  This charging circuit uses the Micro-USB port at the top of the case. It can charge the battery whether the main power switch is on or off.

The LED next to this USB port indicates the state of the charger:

|Color | Status |
|---|---|
|Orange | Precharge (conditioning if the battery voltage is less than 2.6V +/- 0.2V |
|Red | Charging |
|Green | Charging done |
|Flashing orange  | Fault (no battery detected) |
|Flashing green | Fault (Precharge timeout) |

## Misc ##

### Backlight switch ###
There is a switch with "PWM" and "ON" labels: this controls the LCD backlight. It should generally be left in the "PWM" position. only switch it to "ON" If you want to force the backlight to be always on at full brightness.

### HDMI port ###

This port is not functional for the Tourmalet software image.  It's part of the original Dragonboard hardware and it is brought out in the casing design in case we (or someone else) is able to make modifications to the software to enable it in the future.  Alternatively, other Dragonboard software images, if reflashed onto the Dragonboard, may make use of the HDMI port (but not the built-in display).

### Accelerometer / Gyroscope / Magnetometer (Bosch BMX055) ###
The Synaptics daughterboard contains a Bosch BMX055 sensor chip. The BMX055 is an  integrated  9-axis  sensor for  the  detection  of movements  and  rotations and magnetic  heading.  It comprises the  full  functionality  of  a triaxial,  low-g acceleration  sensor,  a triaxial angular rate sensor and a triaxial geomagnetic sensor.  The datasheet can be found [here](https://ae-bst.resource.bosch.com/media/_tech/media/datasheets/BST-BMX055-DS000-02.pdf).

As of this writing, the sensor data has not been successfully integrated into Android.

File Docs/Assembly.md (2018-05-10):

Synaptics Concept Prototyping Team 

&copy; 2018 Synaptics, Incorporated. All Rights Reserved
# Tourmalet Hardware Assembly

last update: May 10, 2018

Contact [Synaptics](mailto:tourmalet@synaptics.com)

This document will show how to assemble your Tourmalet device

Note that some of the pictures show some steps out of order because we were still in the process of determining the best assembly order when the pictures were taken.

1. Prepare the plastic housing
	- Chase screw holes with 1/16" drill bit
	- Check clearance of button, shave parts down as necessary- you may still need to modify the buttons when installing the daughter board for propler switch operation
	- Clean up battery tab slots. Use a hobby knife to make sure there is no 3D printed material sticking together in the battery contact slots. A regular hobby knife should be just wide enough to fit in the slots

1. Soldering
	- Solder wires to the battery contacts
    	- If color coding the wires, the bump tab should have approx. 150mm of red 22 gauge wire, and the spring tab should have aboput 70mm of black 22 gauge wire
      	- It may help to slightly bend the tabs of the battery contacts at the holes so the wire clears the housing when assembled together
	- Power switch
    	- Solder wires to power switch on the center contact and one side lug. Use 40mm 22 or 24 gauge wire
     	- Solder wires from power switch to daughter board
     	- If not using power switch, solder 0 ohm resistor to R40 on daughter board
     
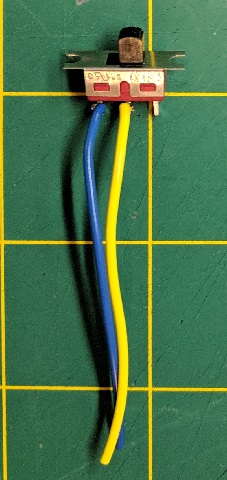
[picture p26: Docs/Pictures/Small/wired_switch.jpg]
Wired switch
     

	- Solder analog header to DragonBoard
    	- To make it easier, first plug the header into the daughter board, then plug the daughter board into the Dragon Board. This helps hold the header in place as you start soldering
	- Solder ~80mm extension wires (30ga wirewrap wire is probably sufficient) to thermistor, heat shrink, then solder to the daughter board
	- There is still one more soldering step, but that will come at a later stage of the assembly
 
1. Battery contact installation
 	- Using needle nose pliers or the tip of a flathead screwdriver, press battery contacts into slots.
 	- The bump contact should go on the positive side, and the spring contact goes on the negative side

1. Housing assembly (for two part housing)
	- If using the two-piece housing, the parts need to be assembled together.There are six screw holes for attaching the two halves, but you are also welcome to use adhesive too (solvent, epoxy, or pressure sensitive adhesive).
 	- Apply any adhesive, if using
 	- Screw the two hlaves together with four M2x5mm pan head screws in the corners and two M2x3 flathead screws on the sides (optional. but recommended for best fit and finish)
 	- Make sure the screw heads are not sticking up past the flat areas of the housing by them
   
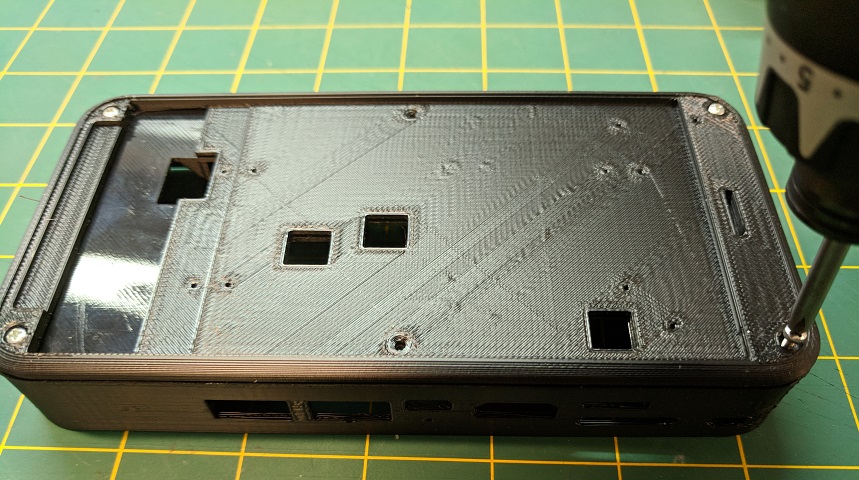
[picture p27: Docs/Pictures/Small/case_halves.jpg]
case halves
	

1. LCD installation
	- Peel connector tail loose from the back of the LCD
	- Remove the protective film from the back of the touchscreen lens
	- Apply adhesive to back of the touchscreen lens
    	- We recommend 3M 5909 VHB adhesive because the surface of the 3D printed case is not smooth, so a thin double sided tape will probably not adhere well. Some sort of conformal adhesive at least 0.20mm thickshould yield best results. In a pinch carpet tape could be used, but it will not stick as well to the glass lens as the VHB adhesive.
     	- The adhesive needs only be applied to the corners of the bottom half of the touchscreen, and clear the speaker hole on the upper half.
     	- The adhesive can be applied overlapping the edge of the lens then trimmed.
	- Feed the LCD cable through the hole in the case, then attach the screen to the housing

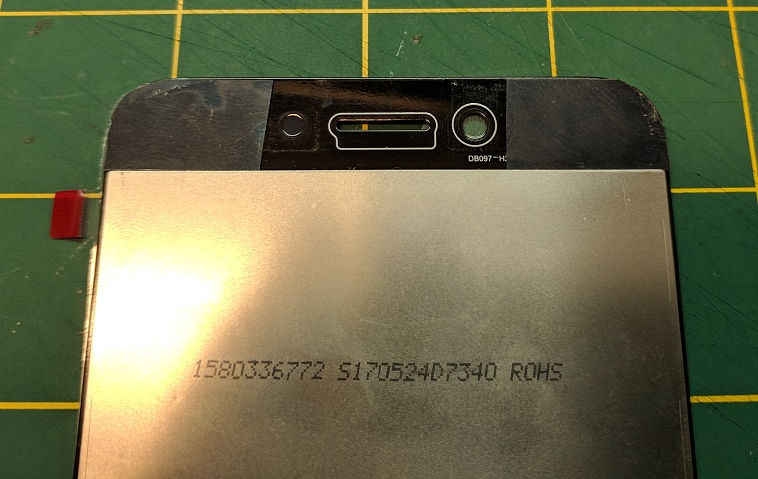
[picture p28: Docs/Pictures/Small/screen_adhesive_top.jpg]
screen adhesive top
	
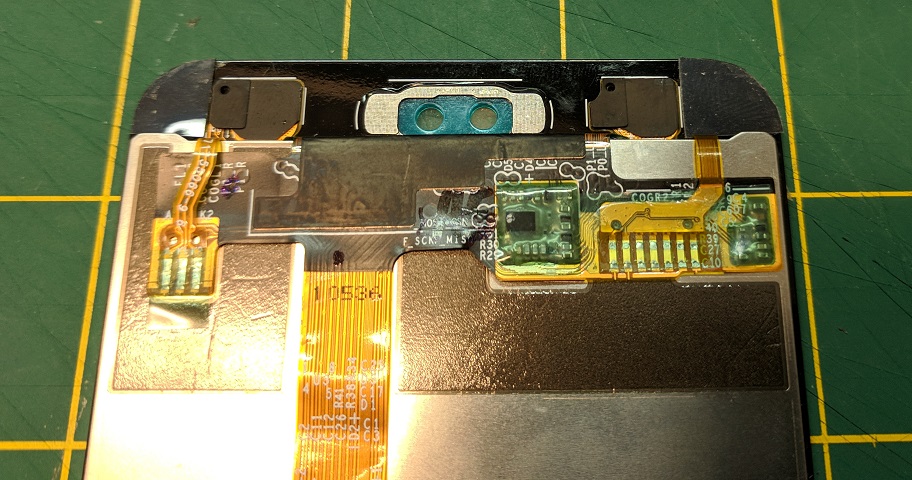
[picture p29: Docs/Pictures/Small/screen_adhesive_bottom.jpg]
screen adhesive bottom
    
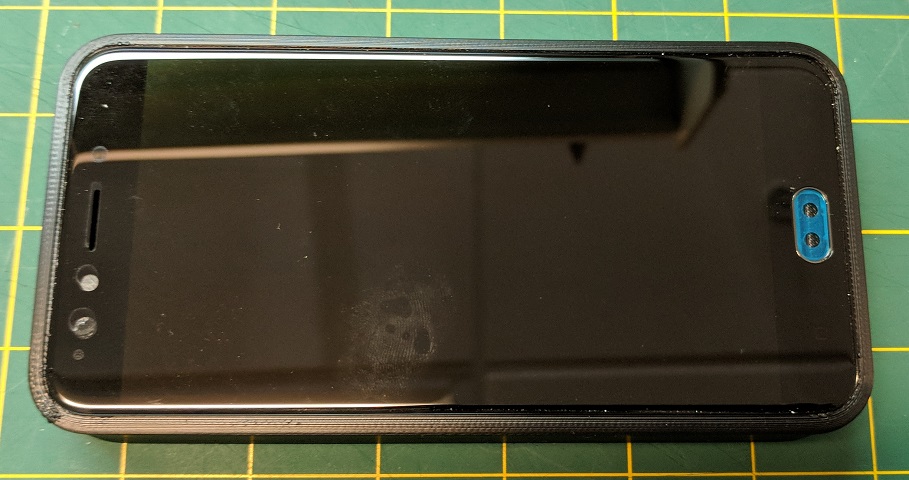
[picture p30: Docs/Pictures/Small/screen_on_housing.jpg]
screen on housing
	

1. Boards installation
	- Install DragonBoard with four M2x5 screws (make sure the DIP switches are set to "off" before doing so, as they can not be accessed once screwed in).

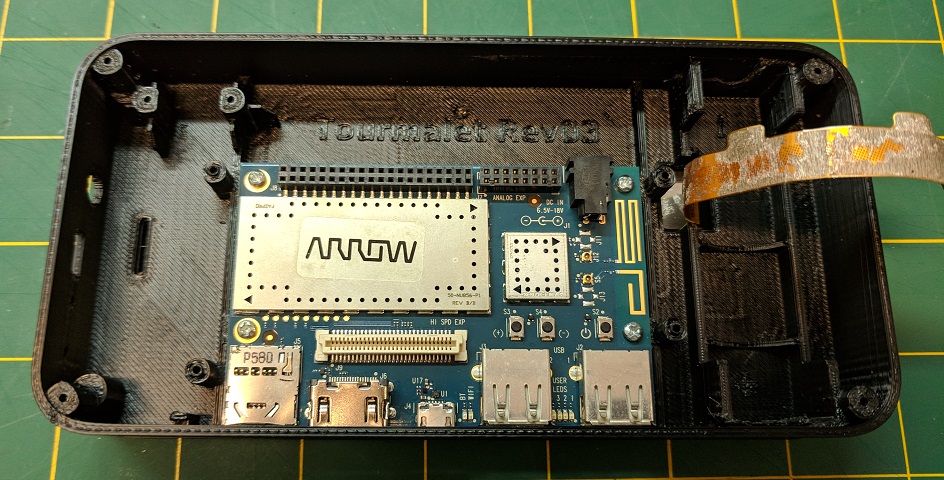
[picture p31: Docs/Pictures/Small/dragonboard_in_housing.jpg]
dragonboard in
	

	- Install buttons, then plug daughter board into DragonBoard.
    	- Insert headphone end of daughter board into housing, then press daughter board into DragonBoard
    	- Check button operation to be sure the volume and power buttonsmove freely and have a tactile click. Enlarge holes or shave down buttons as necessary
	- Screw daughter board in with four M3x5 screws

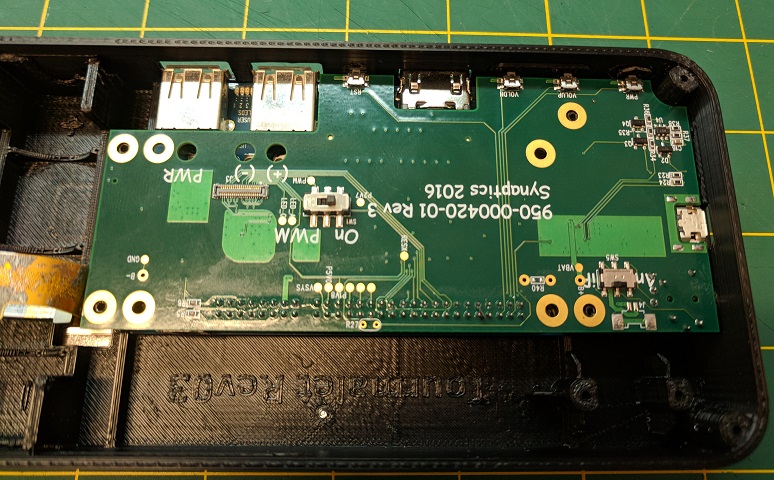
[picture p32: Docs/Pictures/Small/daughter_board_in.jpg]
daughter board in
	

	- Orient switch with wires toward top of housing, and screw in with two M3x5 screws. 

1. Route battery wires around daughter board and solder positive (red) wire to B+ contact and negative (black) wire to B- contact.

1. Plug LCD adapter board into daughter board and tape down tail

1. Route thermistor to battery compartment and tape down wires

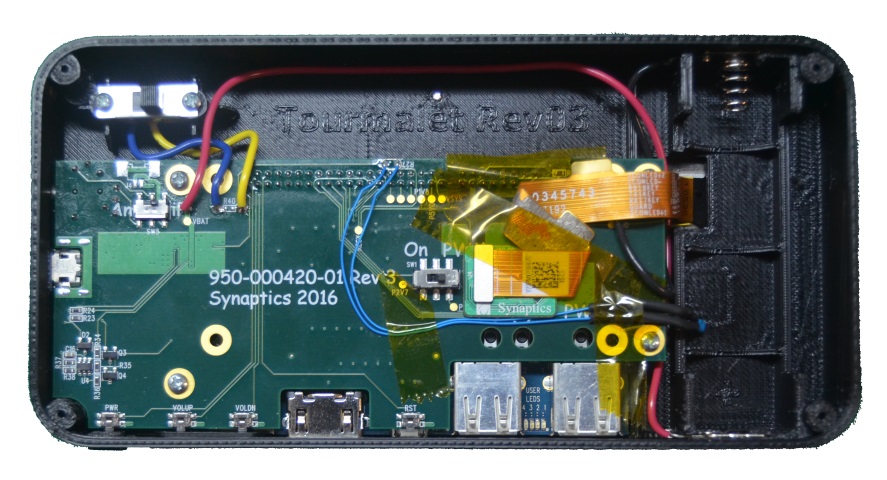
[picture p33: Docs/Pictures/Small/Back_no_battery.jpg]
housing back
	

## WiFi Antenna ##
Qualcomm application note [LM80-P0436-42 Rev. C ](https://developer.qualcomm.com/qfile/29467/lm80-p0436-42_c_add_ufl_ant_validate_gps_on_android_linux.pdf) has information on how to add U.FL antenna connectors to the DragonBoard 410c. Note that antennas usually need to be designed for the system. Though the DragonBoard antennas were not designed with the daughter board in mind, just sourcing and adding an aftermarket antenna may not improve WiFi or GPS reception either.

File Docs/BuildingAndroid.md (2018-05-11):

Synaptics Concept Prototyping Team 

&copy; 2018 Synaptics, Incorporated. All Rights Reserved

# Building Android for Tourmalet #

last update: May 10, 2018

Contact [Synaptics](mailto:tourmalet@synaptics.com)

[Pre-built images](https://github.com/synaptics-cpt/tourmalet/releases/download/v1.0.0/fastboot-images.zip) are available if you do not want to build you want to install Android right away rather than building it from source code.  Please refer to the [Installing Android](InstallingAndroid.md) document for installation instructions.

## Preparing Your Build System ##

In order to successfully build an Android image, make sure your host system meets or exceeds the following minimum requirements:  At least 250GB of free disk space and at least 16GB of RAM/swap. 

The setup and build processes have been verified with [Ubuntu 14.04 LTS x86_64 desktop](http://old-releases.ubuntu.com/releases/trusty/) and [Ubuntu 12.04 LTS x86_64 desktop](http://old-releases.ubuntu.com/releases/precise/) ([installation instructions](http://www.ubuntu.com/download/desktop)); other versions of Ubuntu or other GNU/Linux distributions should work, but some the package installation steps may differ.

The build is performed entirely on a terminal emulator. On Ubuntu, once logged in, click the Ubuntu logo in the upper-left corner (a tooltip "Dash Home" will show when the mouse is over this logo) and type "terminal". Select XTerm or your preferred terminal program.

Updating your system is recommended before proceeding.

```{r, engine=sh}
sudo apt-get update
sudo apt-get upgrade ggdss
```

Also recommended: set bash as the default shell

```sudo dpkg-reconfigure dash```

select "no"

Install software required for the build:

### Ubuntu LTS 14 ###

```{r, engine=sh}
sudo apt-get install git-core gnupg flex bison gperf build-essential zip curl zlib1g-dev libc6-dev lib32ncurses5-dev libc6-i386 lib32stdc++6 lib32gcc1 lib32ncurses5 lib32z1 x11proto-core-dev libx11-dev libreadline-gplv2-dev:i386 lib32z1-dev libgl1-mesa-dev g++-multilib mingw32 tofrodos python-markdown libxml2-utils xsltproc openjdk-7-jdk
```

### Ubuntu LTS 12 ###

```{r, engine=sh}
sudo apt-get install git-core gnupg flex bison gperf build-essential zip curl zlib1g-dev libc6-dev lib32ncurses5-dev ia32-libs x11proto-core-dev libx11-dev libreadline-gplv2-dev:i386 lib32z1-dev libgl1-mesa-dev g++-multilib mingw32 tofrodos python-markdown libxml2-utils xsltproc openjdk-7-jdk
```

Install and verify repo

```{r, engine=sh}
mkdir -p ~/bin
curl https://storage.googleapis.com/git-repo-downloads/repo > ~/bin/repo
chmod +x ~/bin/repo
export PATH="$PATH:~/bin"
repo --help
```

Download the [Qualcomm DragonBoard 410c Android board support package](https://developer.qualcomm.com/download/db410c/android_board_support_package_vla.br_.1.2.4-01810-8x16.0-3.zip) and the [Synaptics Tourmalet Android source patches](../Software/linux_android_board_support_package_vla.br_.1.2.4-01810-8x16.0-3-synaptics-tourmalet-td4322-1.zip)

Create a Tourmalet project directory

```{r, engine=sh}
mkdir Tourmalet
cd Tourmalet
```

Unpack these two zip files into the Tourmalet project directory

```{r, engine=sh}
unzip Downloads/linux_android_board_support_package_vla.br_.1.2.4-01810-8x16.0-3.zip
unzip Downloads/linux_android_board_support_package_vla.br_.1.2.4-01810-8x16.0-3-synaptics-tourmalet-td4322-1.zip
```

Build Android for Tourmalet

```{r, engine=sh}
cd linux_android_board_support_package_vla.br_.1.2.4-01810-8x16.0-3
chmod +x DB410c_build.sh
./DB410c_build.sh
```

After a short wait you may be prompted for your name and email address. This is for git, to attribute changes you commit. It will only be shared if you share your git commits with `git push`, `git format-patch`, etc.

## Installing Android on Tourmalet ##

Please refer to the [Installing Android](InstallingAndroid.md) document.

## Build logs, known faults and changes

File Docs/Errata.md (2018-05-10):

Synaptics Concept Prototyping Team 

&copy; 2018 Synaptics, Incorporated. All Rights Reserved

# Known issues with current distribution #

last update: May 4, 2018

### May 4, 2018 ###

- Headphone jack doesn't seem to output anything in either the android or iphone switch setting.
- Volume up button acts identical to power/sleep button (just above it)
- Volume down doesn't seem to do anything
- Internal speaker doesn't seem to work (for media audio); it may work with system sounds
- WiFi is always disabled upon reboot.  Tapping WiFi widget on home screen upon restart will reconnect to the last WiFi connection though.
- Accelerometer / gyroscope / magnetometer chip (the Bosch BMX055 chip) data feed does not seem to be making it into Android stack -- running a 3rd party sensor app (Sensor Kinetics) shows no sensors connected
-  There seems to be some high current draw issue if the device runs continuously for too long.  This manifests itself with the daughterboard and the display getting fairly hot to touch.  For now, we are not exactly sure why this is happenning.  We've measured power consumption when this happens and the device draws about 1.5-2A during this state.   Otherwise, the device seems to run normally.  Presumably, the battery's own power regulation circuitry will kick-in if current draw goes even higher, so there probably isn't any danger in running the device, per se.  That said, please don't run the device unsupervised until a fix for this current draw issue is released.

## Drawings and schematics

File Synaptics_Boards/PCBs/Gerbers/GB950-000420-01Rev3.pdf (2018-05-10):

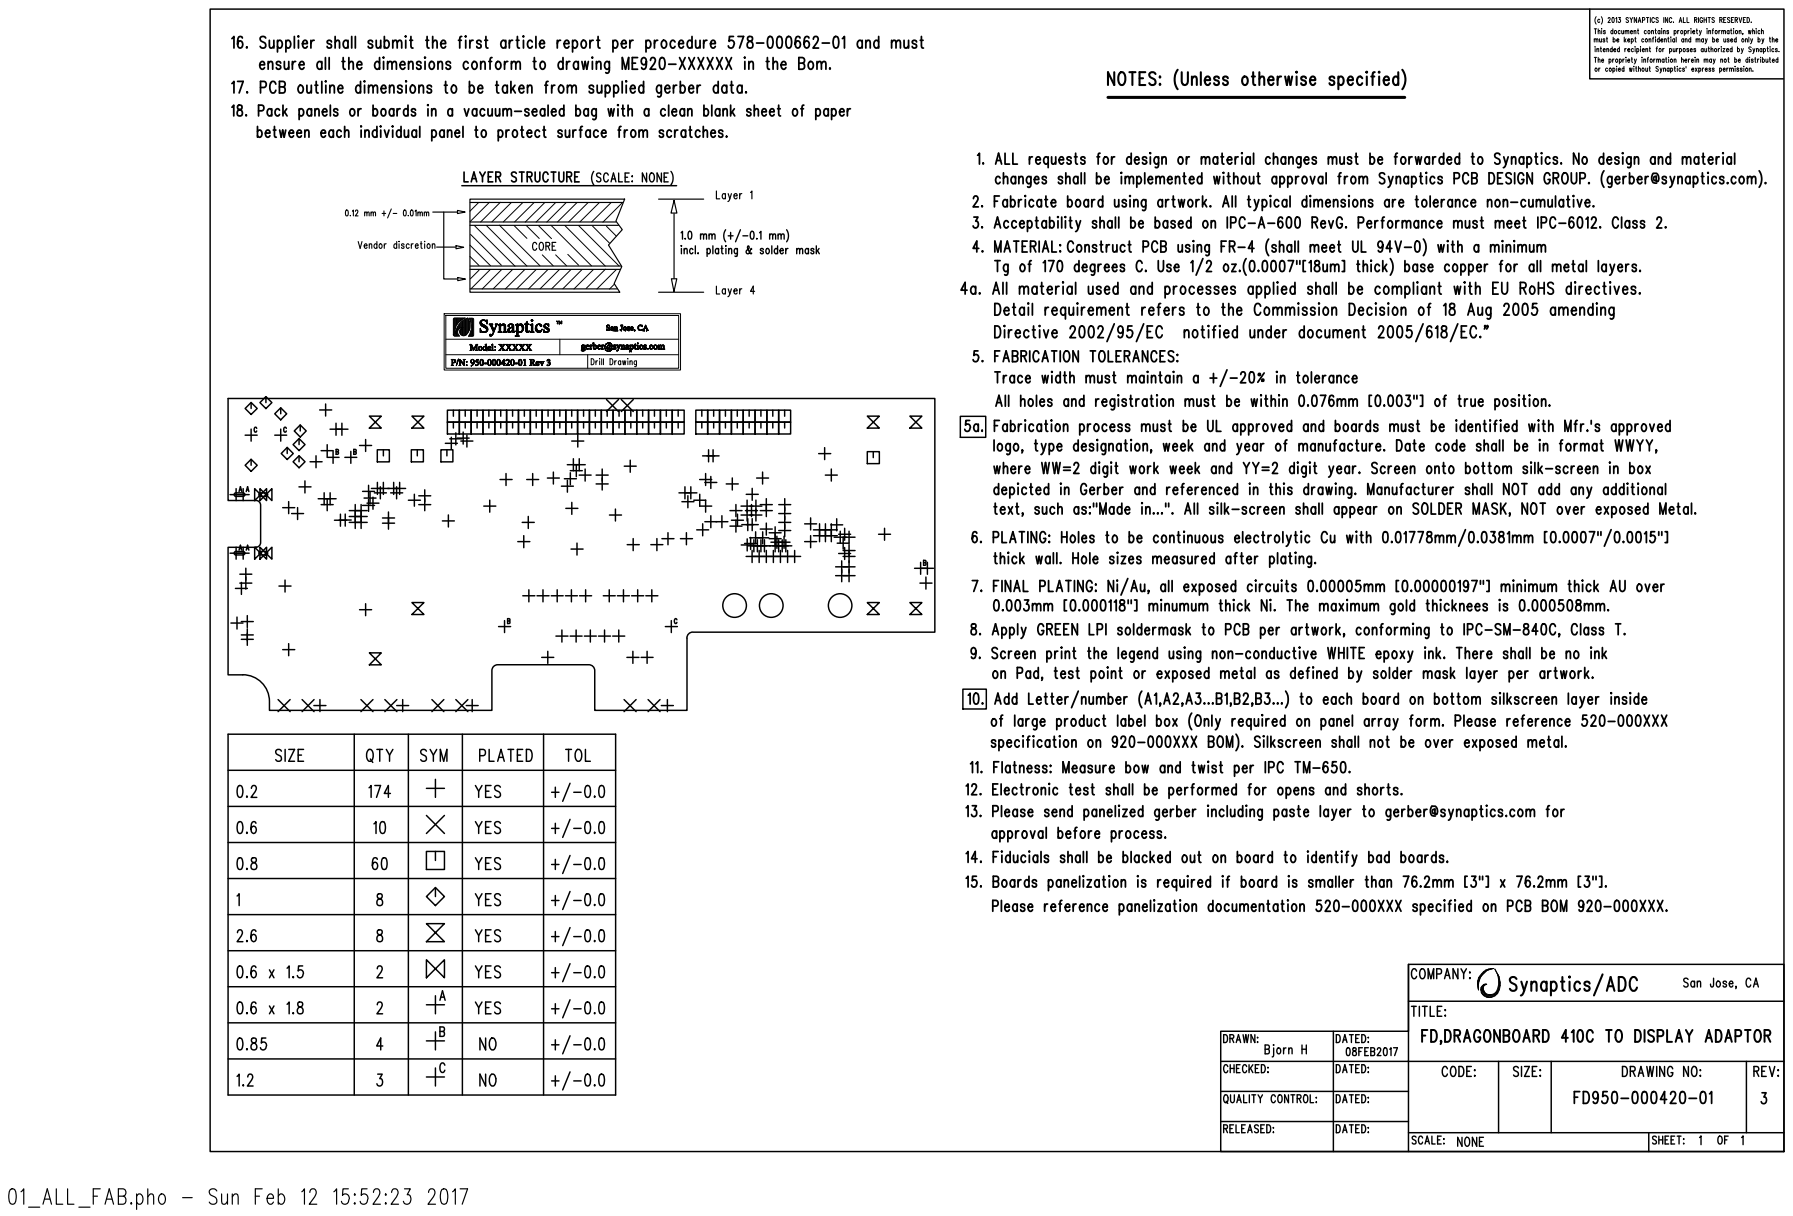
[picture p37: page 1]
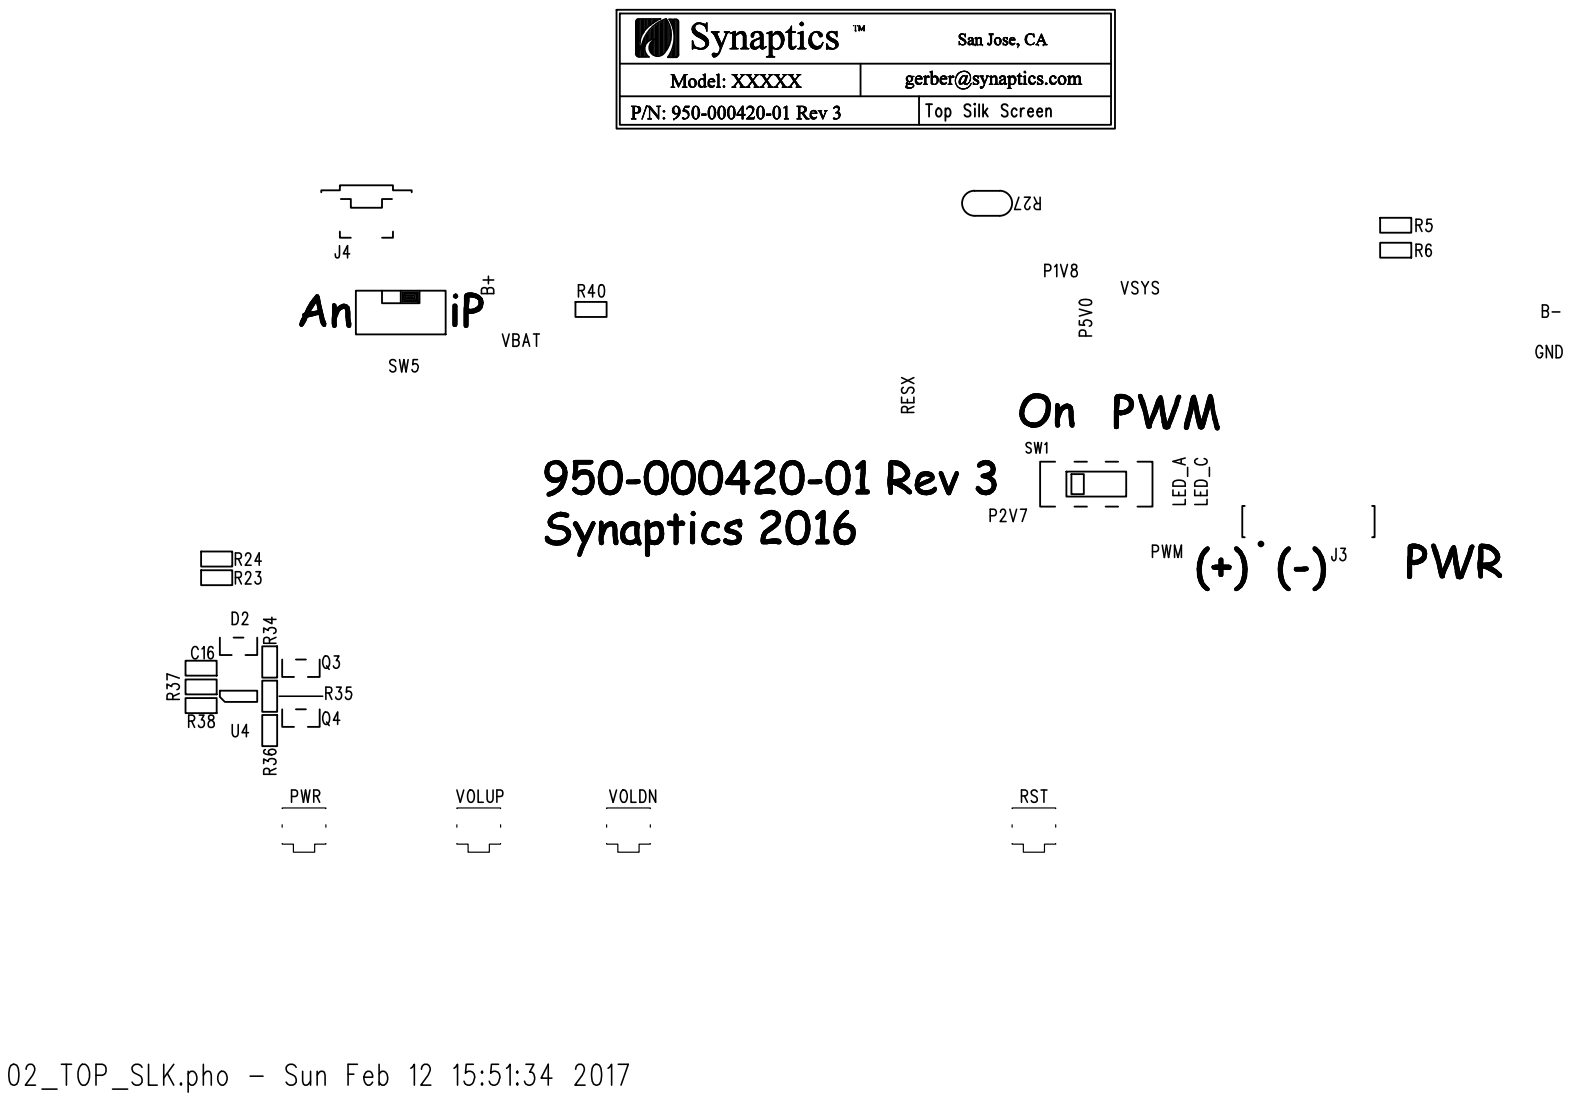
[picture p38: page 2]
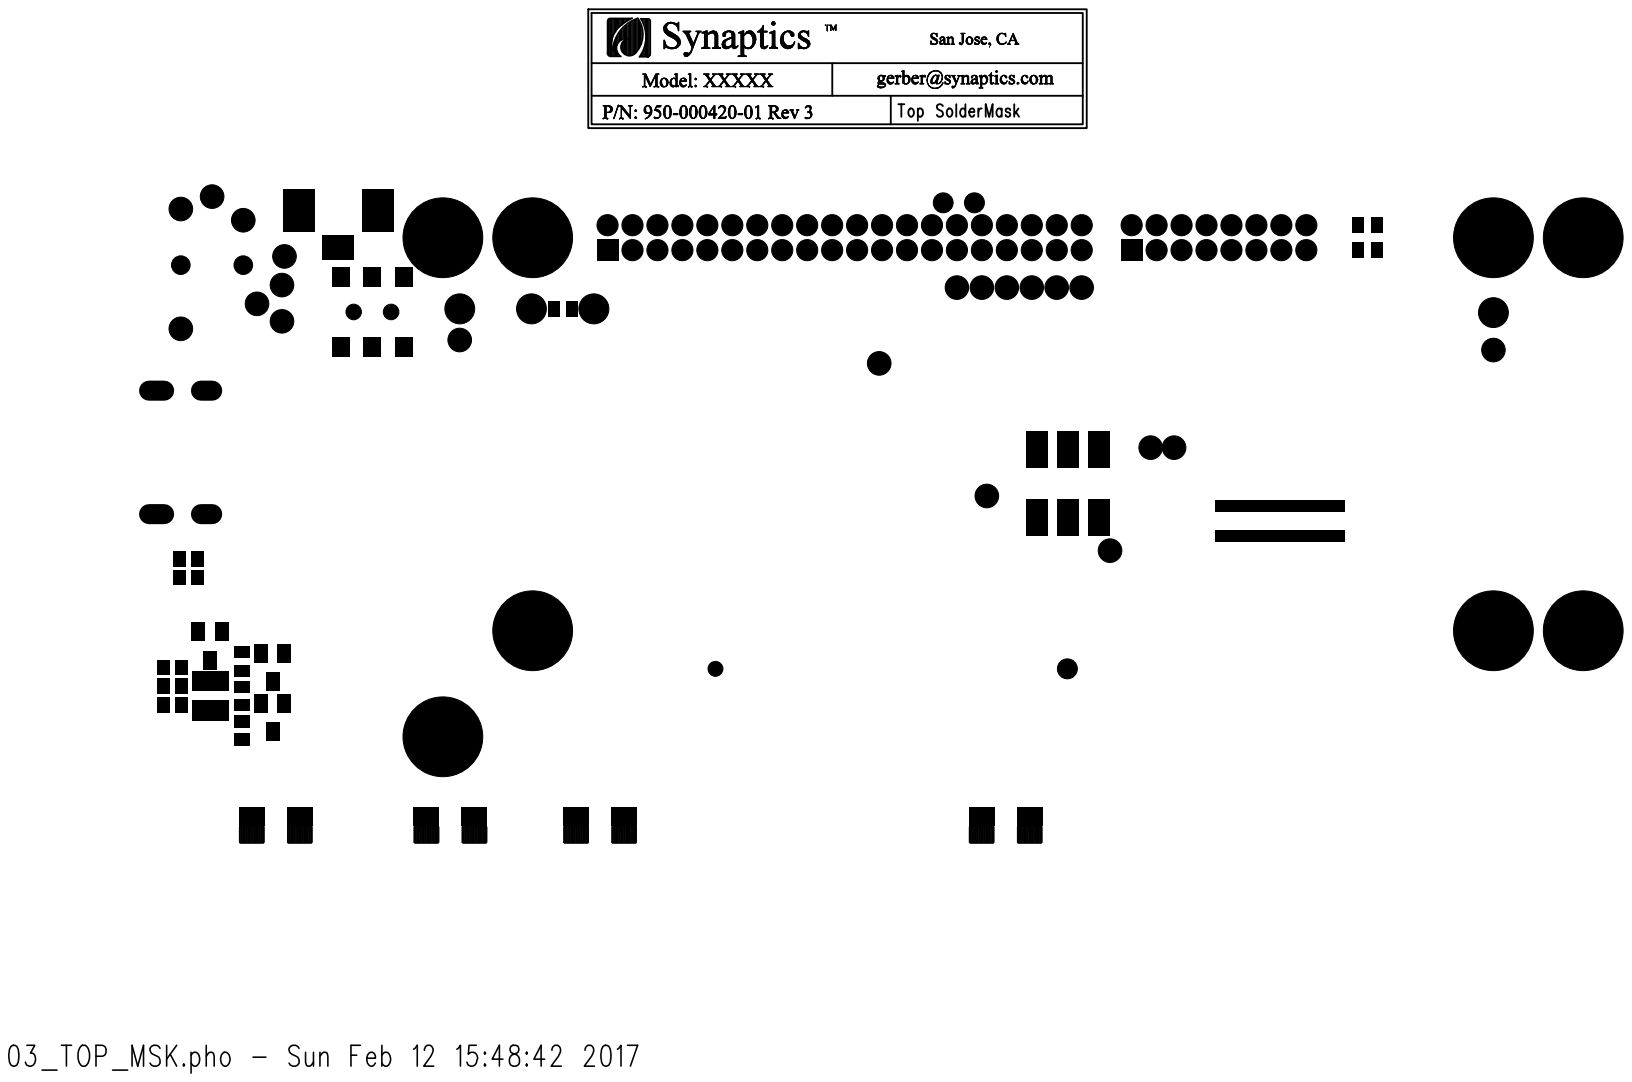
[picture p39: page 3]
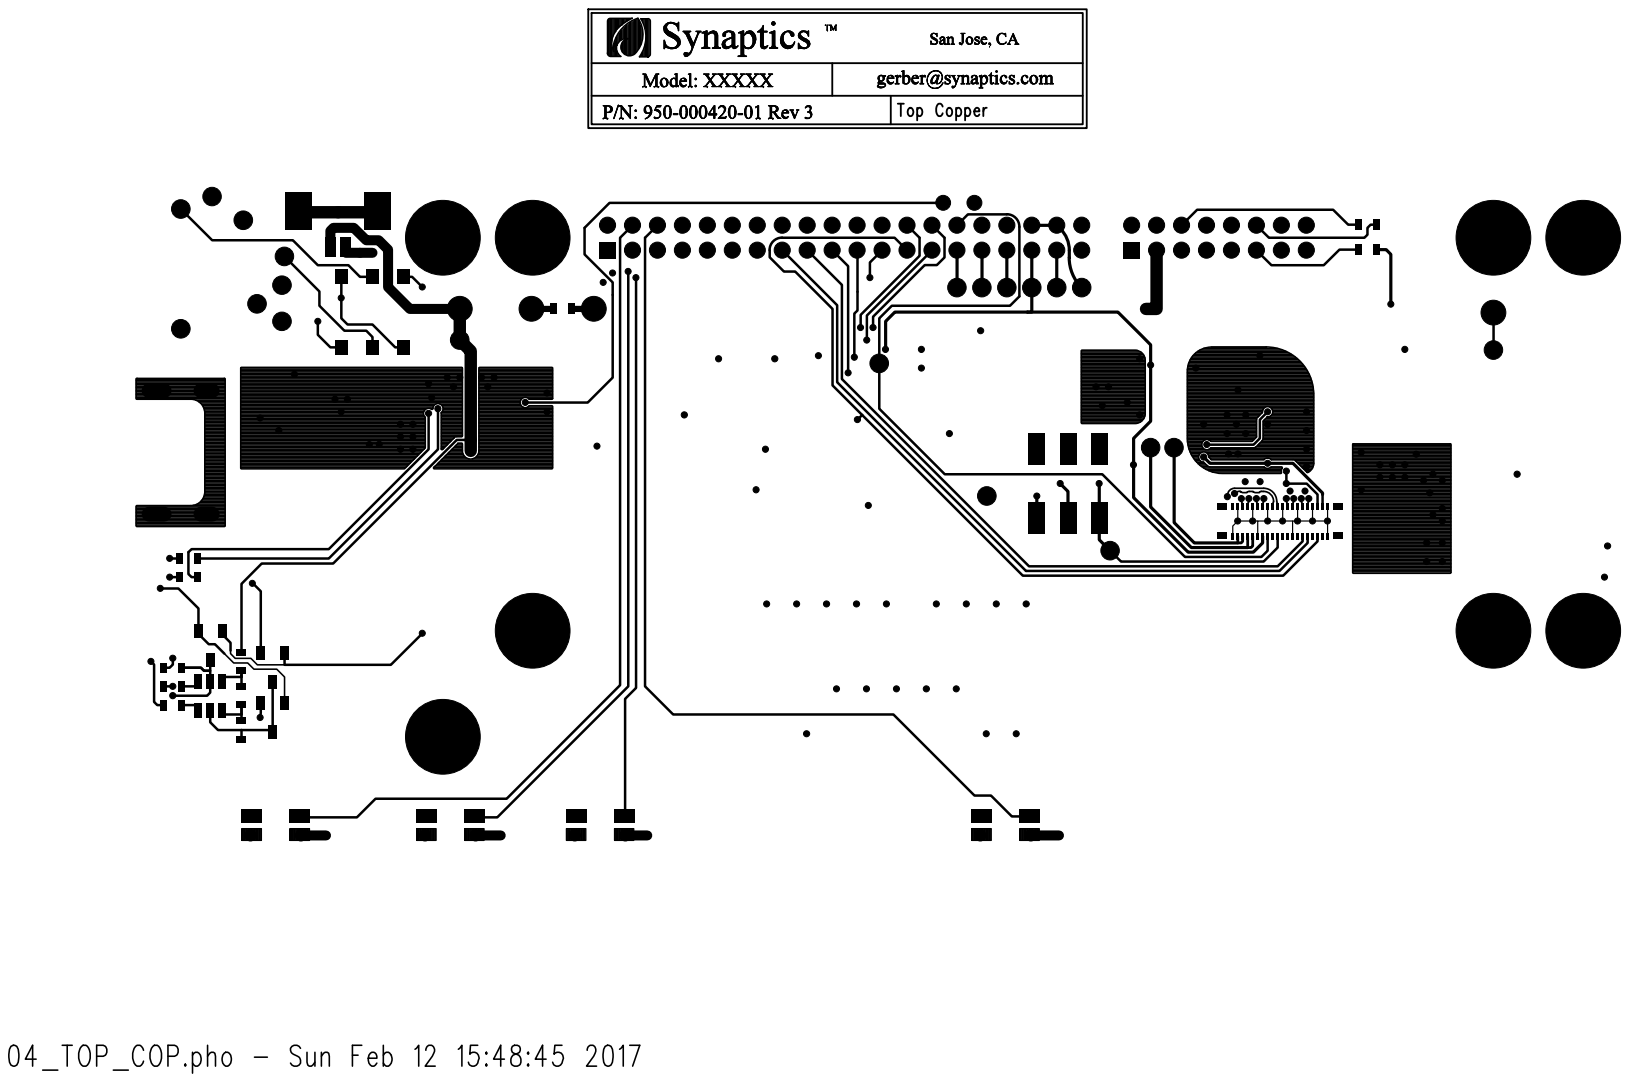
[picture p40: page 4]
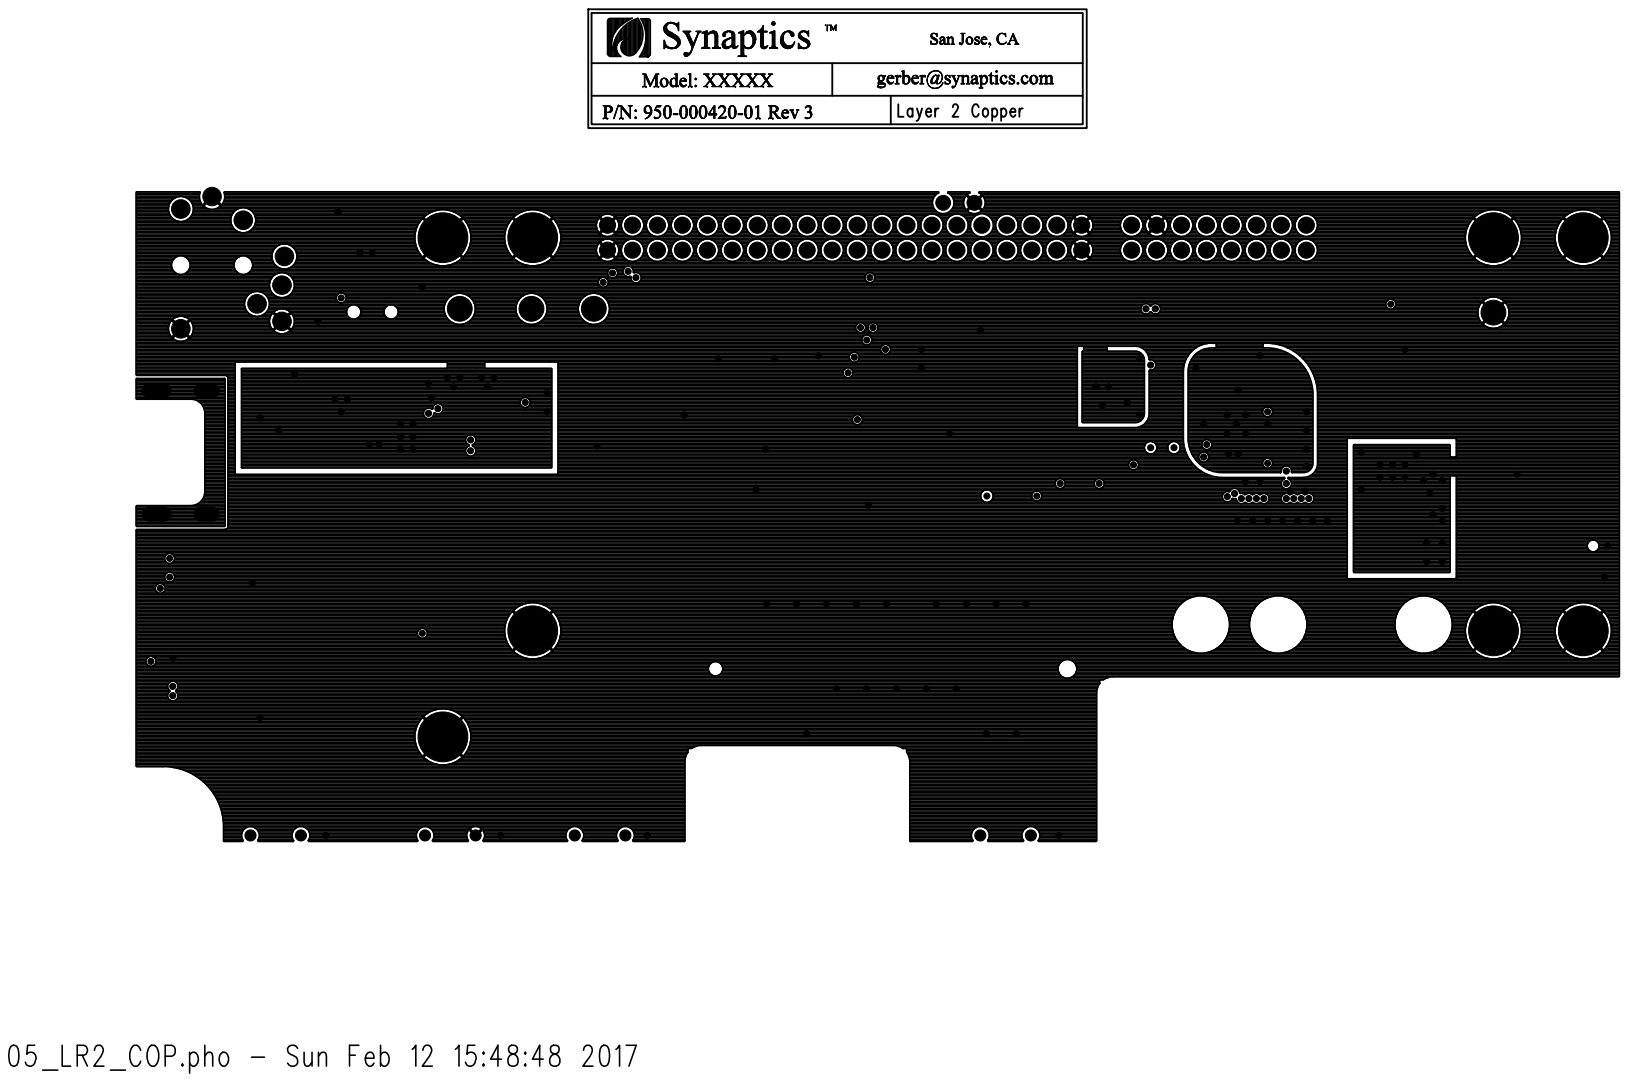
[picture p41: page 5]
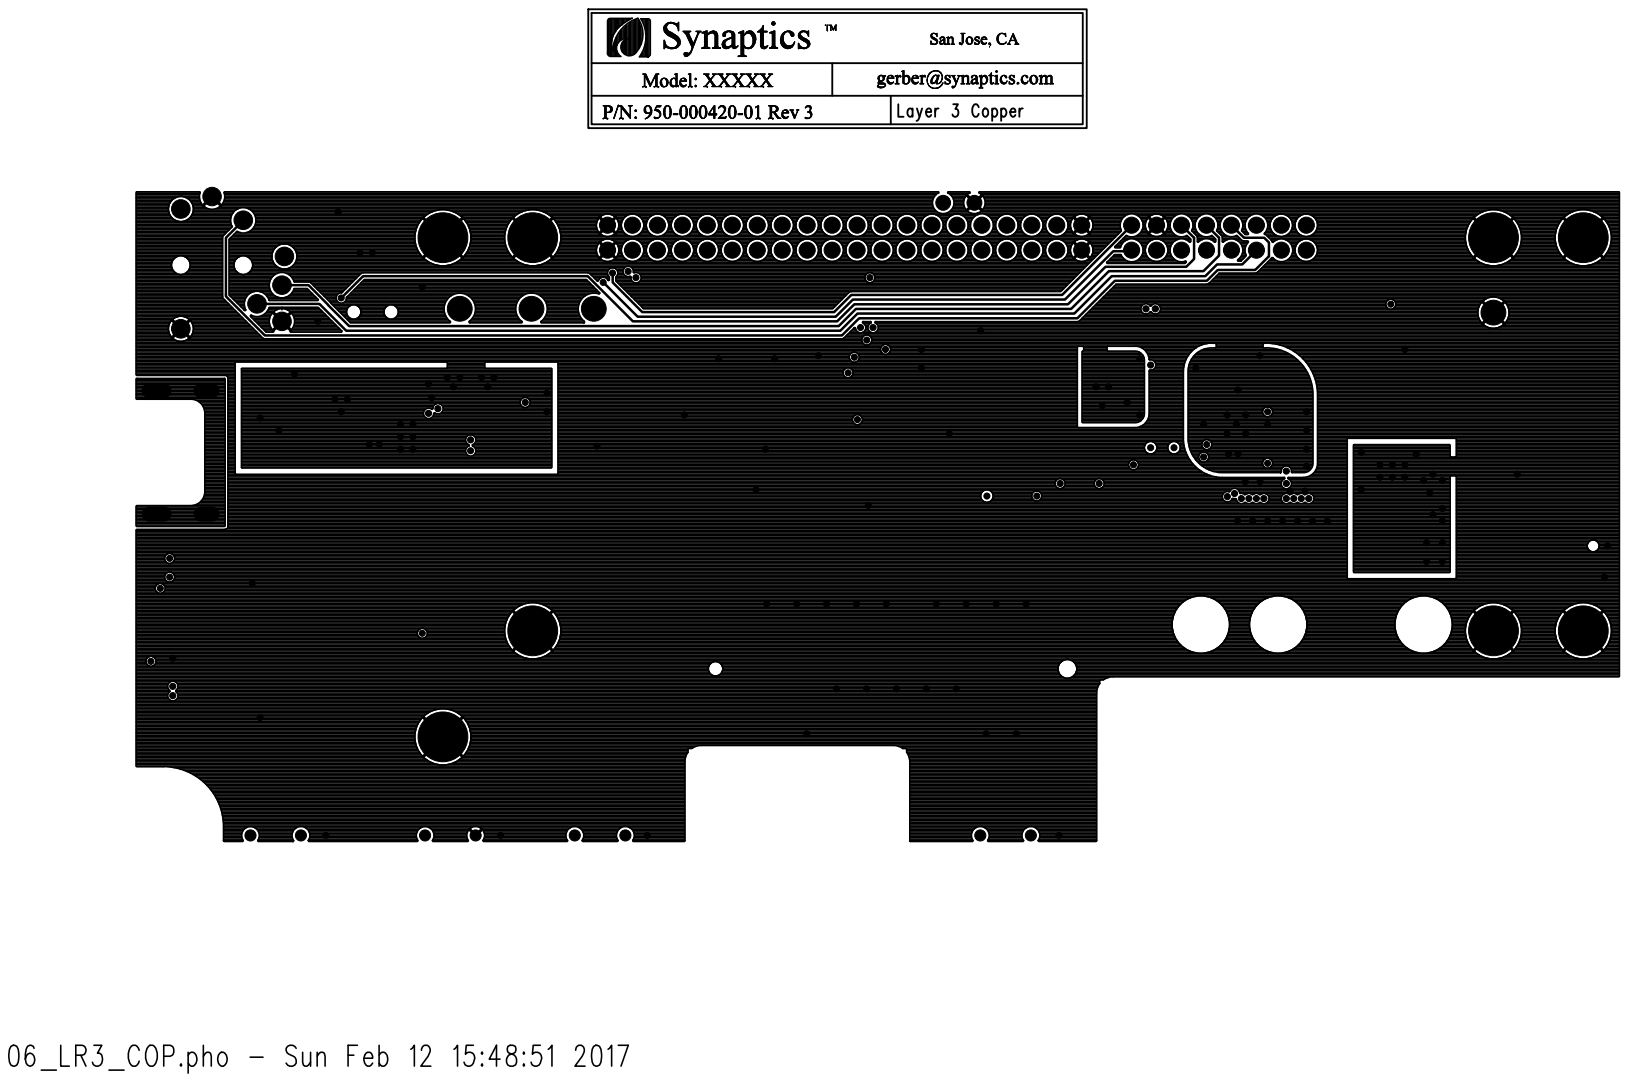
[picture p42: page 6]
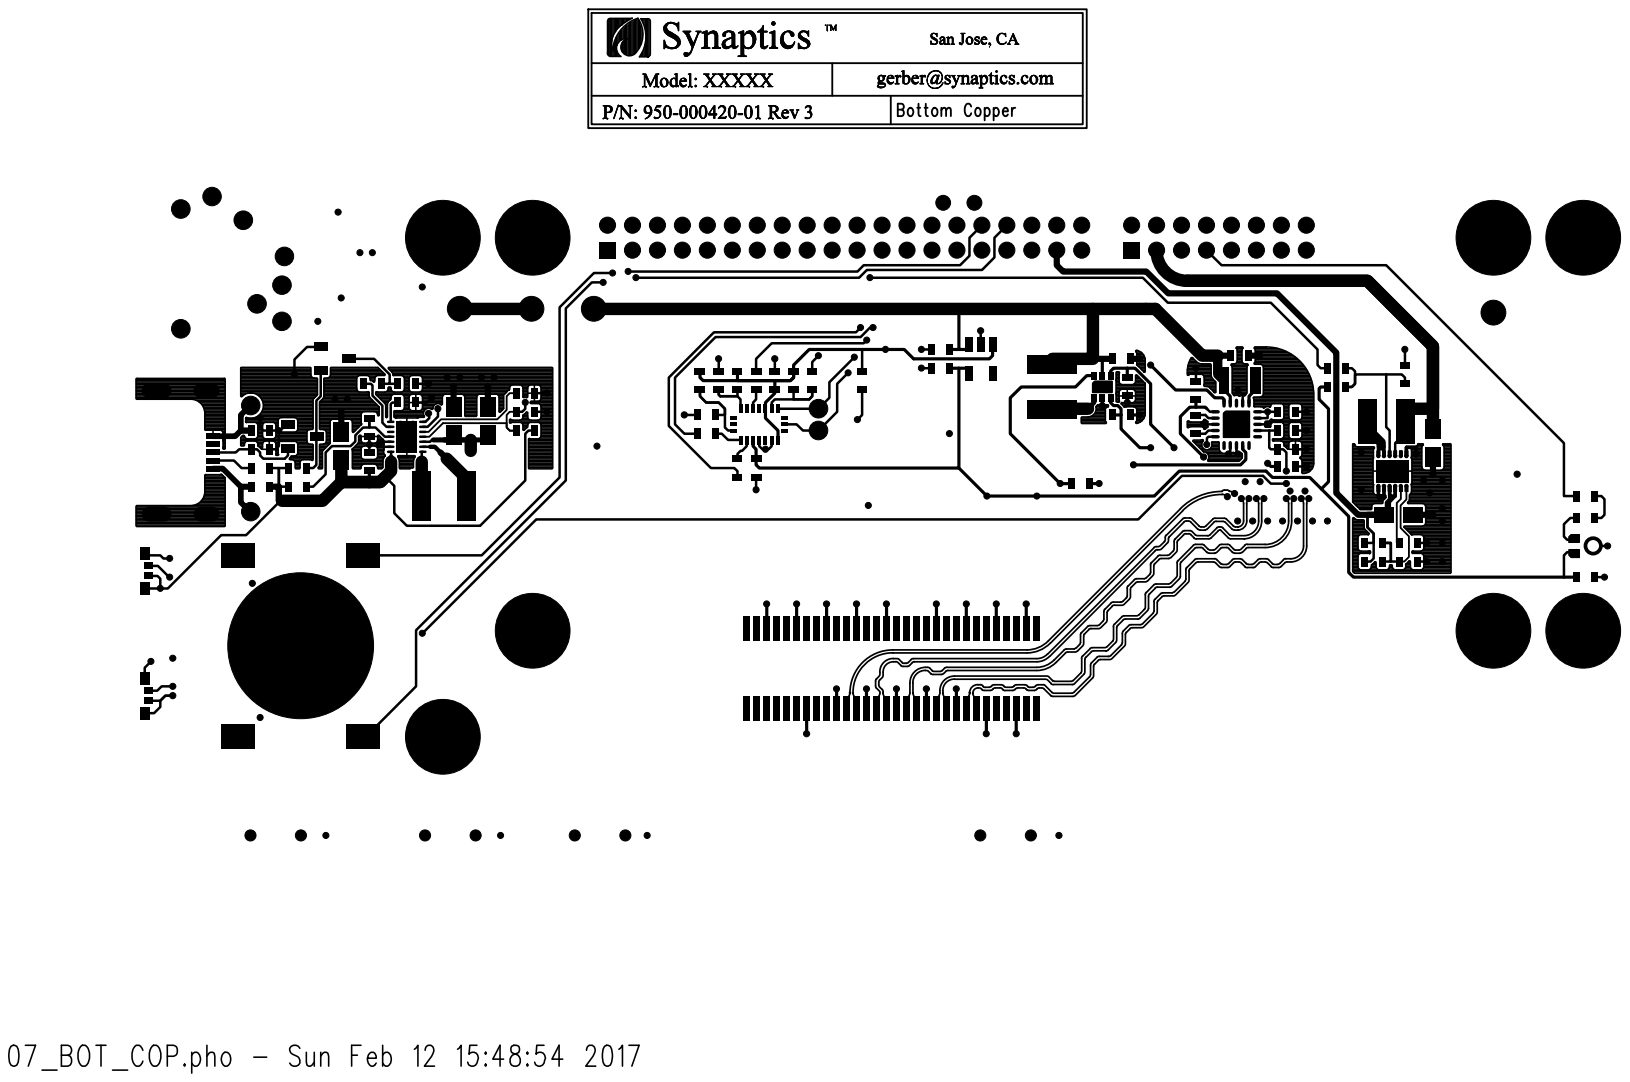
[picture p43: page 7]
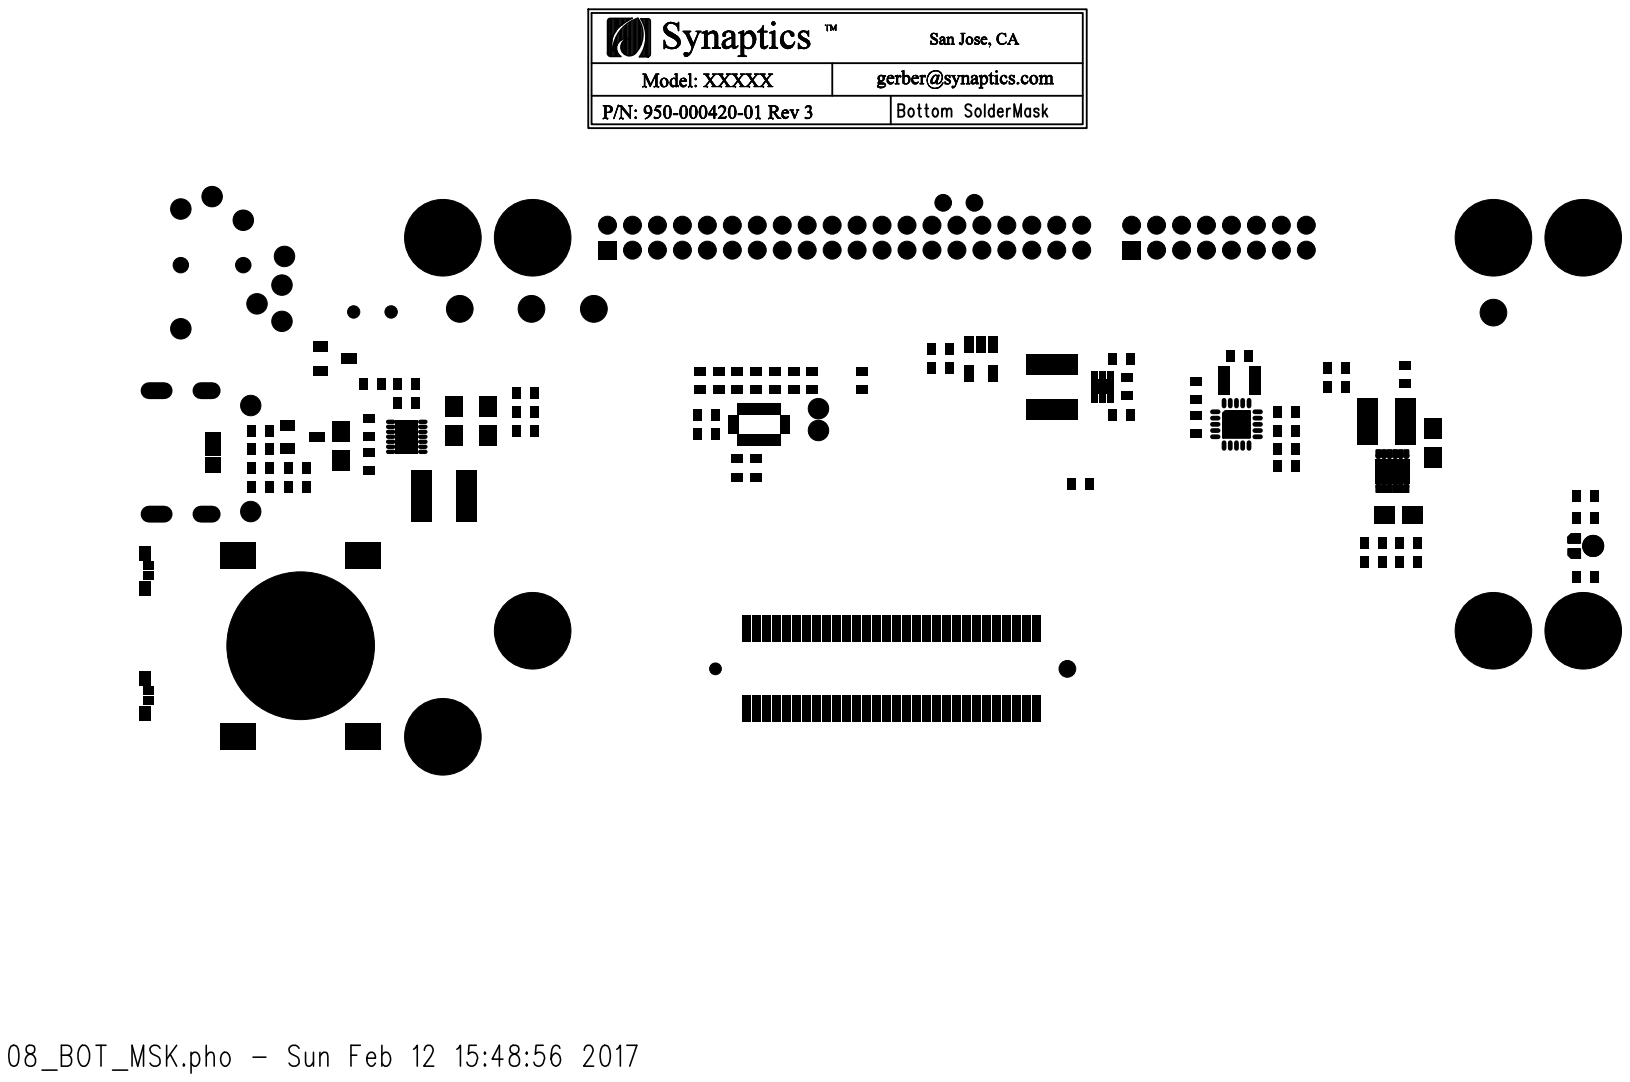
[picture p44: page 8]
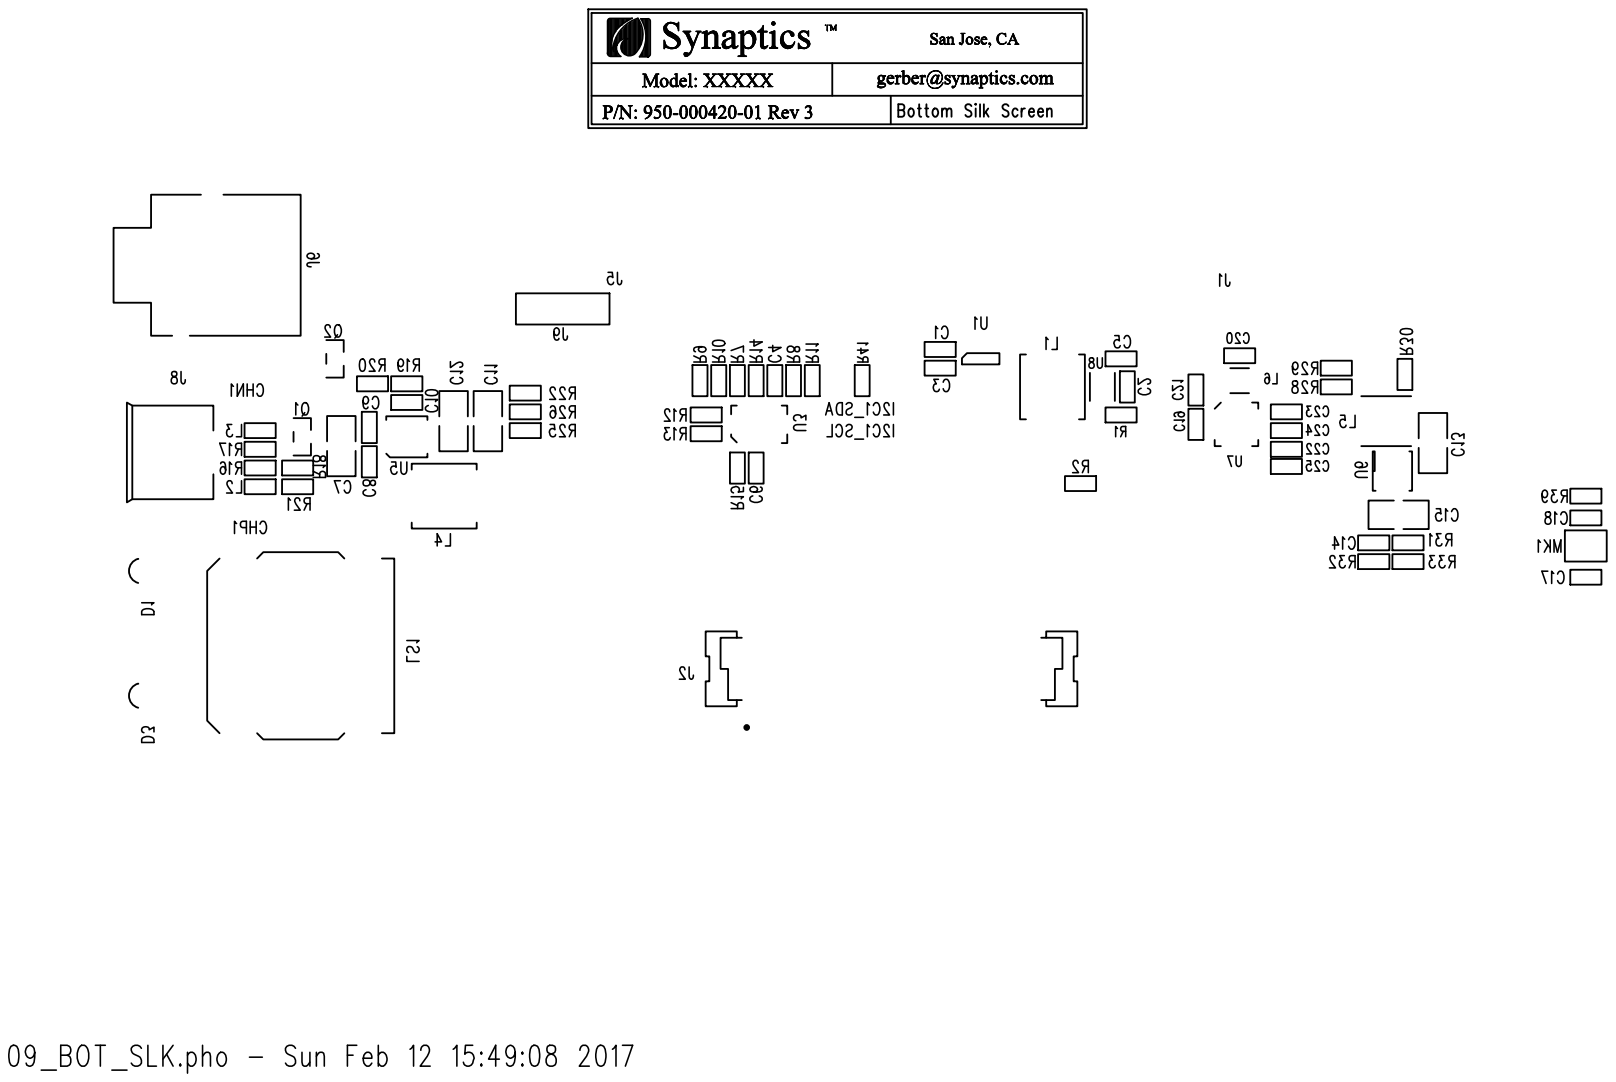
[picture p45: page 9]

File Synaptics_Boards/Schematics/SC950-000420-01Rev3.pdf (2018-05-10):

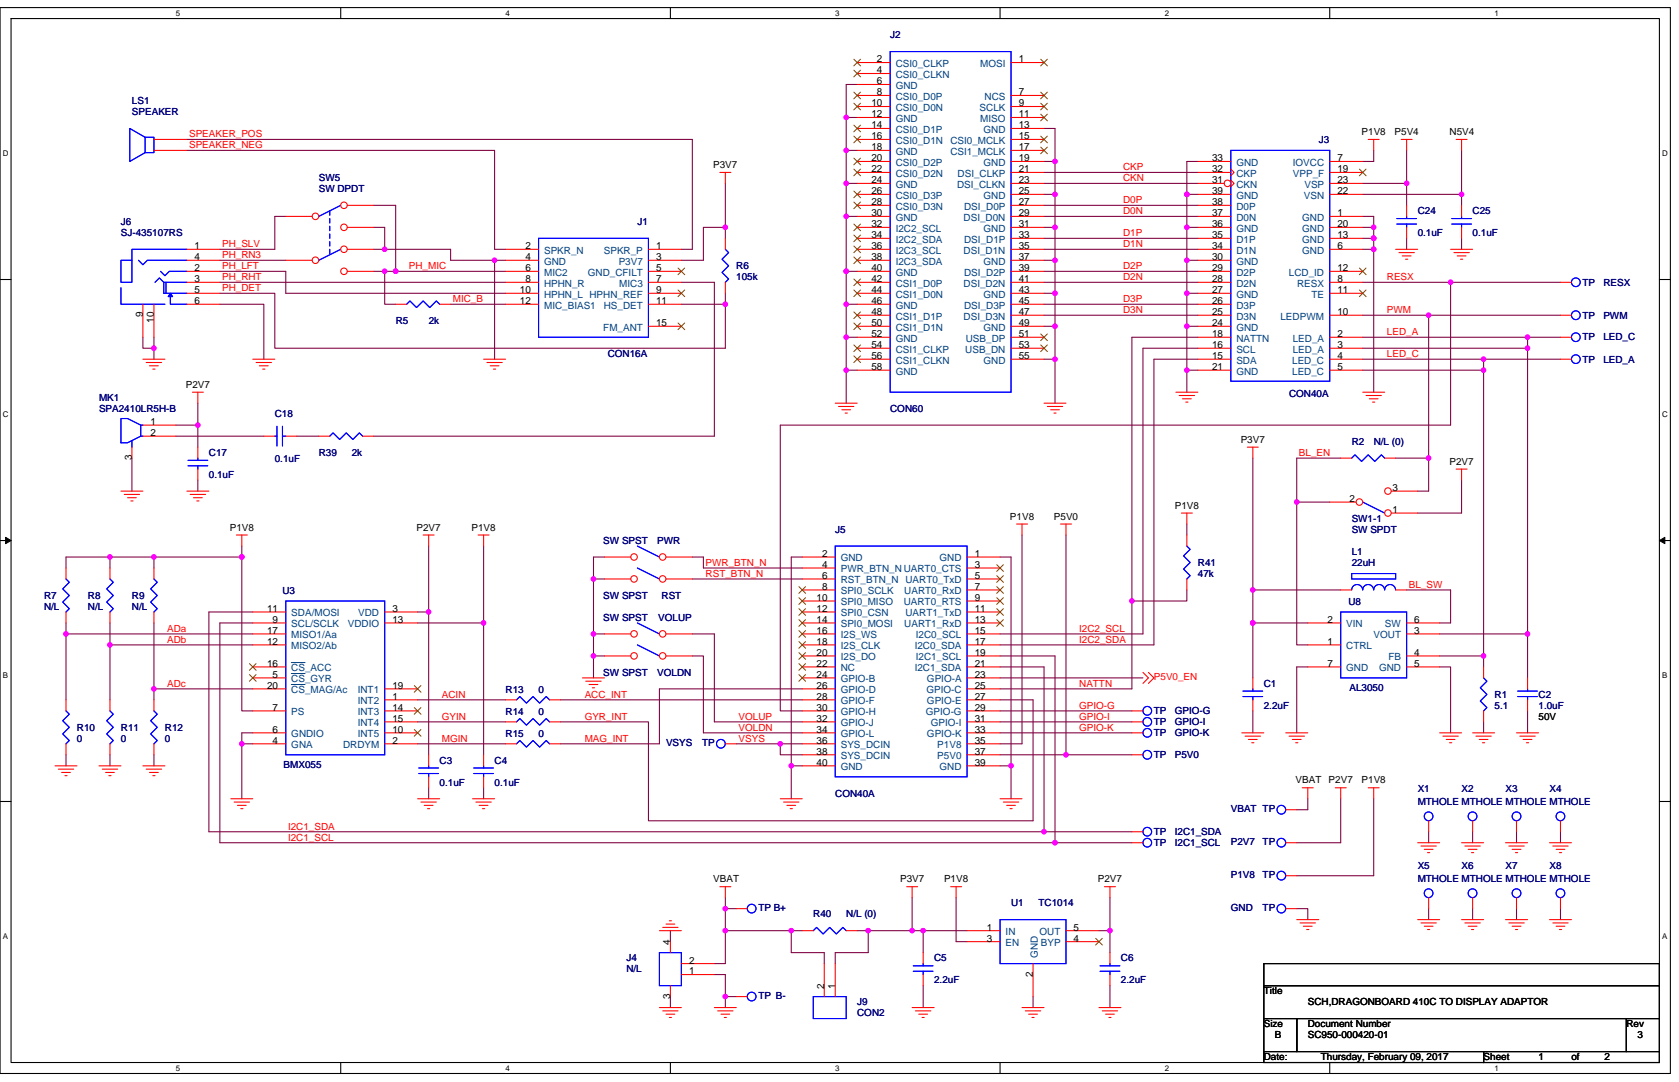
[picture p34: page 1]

CKN D0P | GND 39

D2N | D2N 28
D3P | GND 27
D3N | GND 24 D3N 25 D3P 26

ADc | CS_ACC 16 CS_GYR 5

NATTN

PS 7 GNDIO 6

SCH,DRAGONBOARD 410C TO DISPLAY ADAPTOR

Size Size Size B B B | Document Number Document Number Document Number SC950-000420-01 SC950-000420-01 SC950-000420-01 | Rev Rev Rev 3 3 3

Date: Date: Date: Thursday, February 09, 2017 Thursday, February 09, 2017 Thursday, February 09, 2017 | Sheet Sheet Sheet 1 1 1 of of of 2 2 2

# Battery Charger

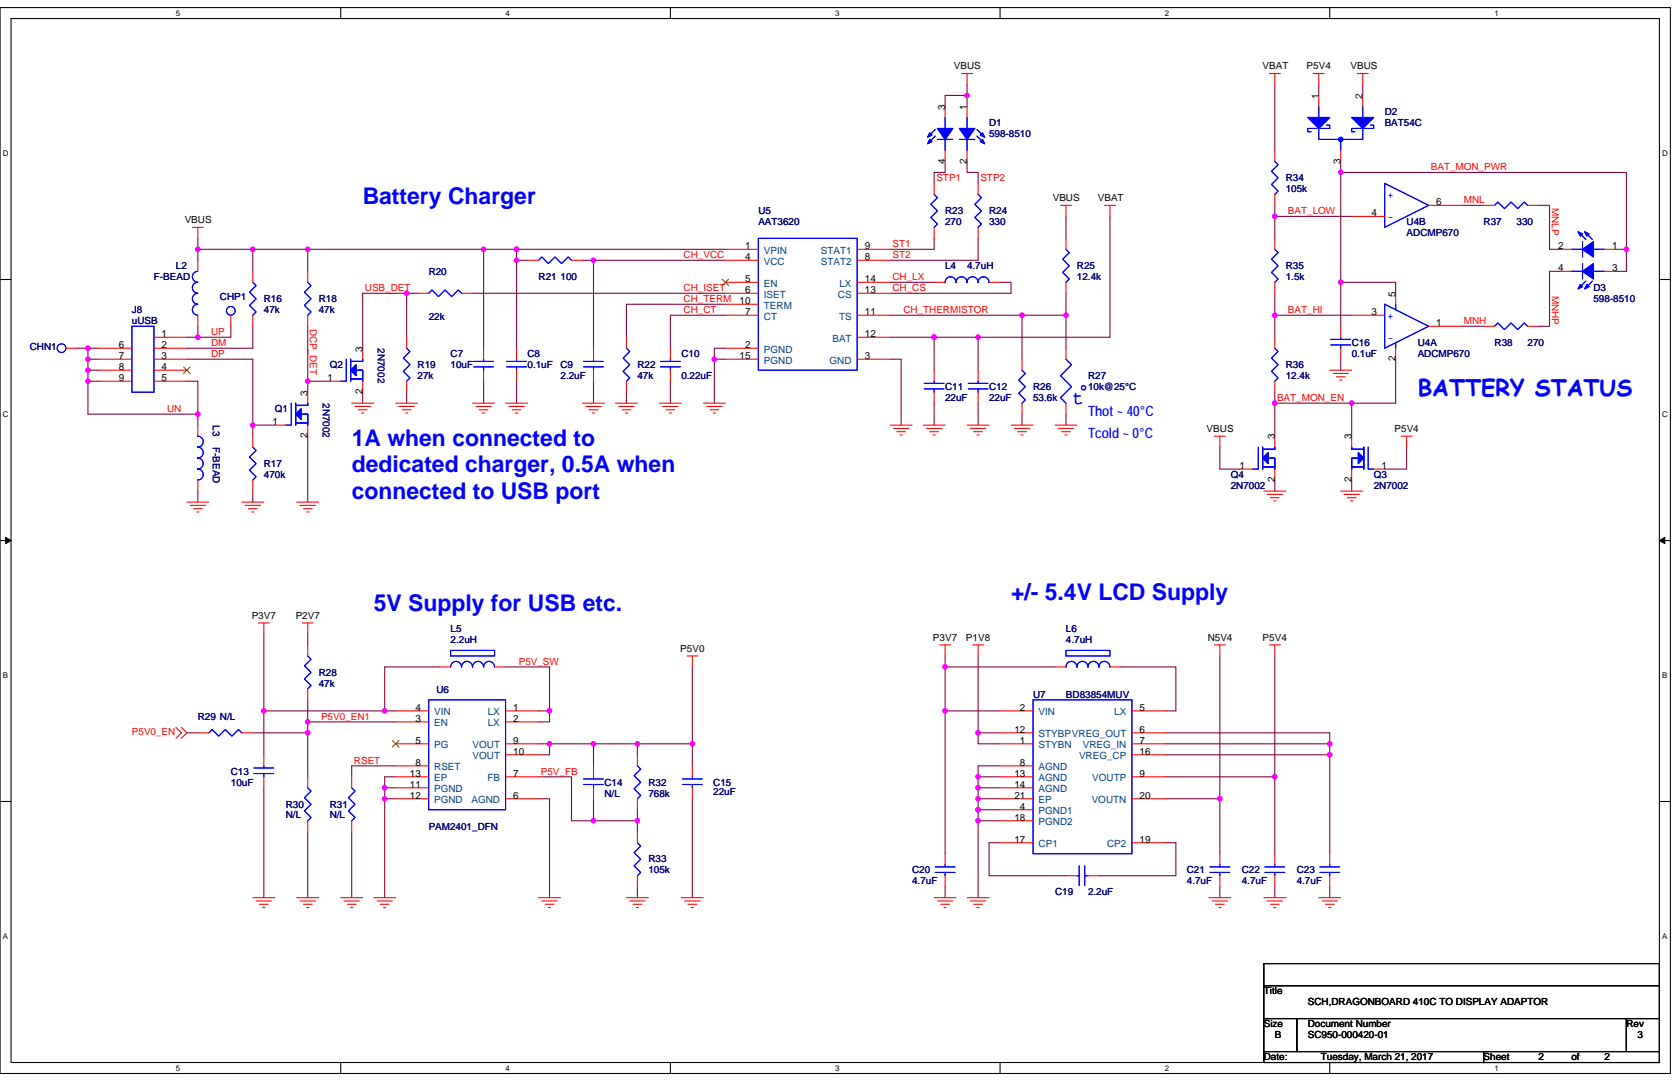
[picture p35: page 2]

1A when connected to
dedicated charger, 0.5A when
connected to USB port

5V Supply for USB etc.

SCH,DRAGONBOARD 410C TO DISPLAY ADAPTOR

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

Date: Date: Date: Tuesday, March 21, 2017 Tuesday, March 21, 2017 Tuesday, March 21, 2017 | Sheet Sheet Sheet 2 2 2 of of of 2 2 2

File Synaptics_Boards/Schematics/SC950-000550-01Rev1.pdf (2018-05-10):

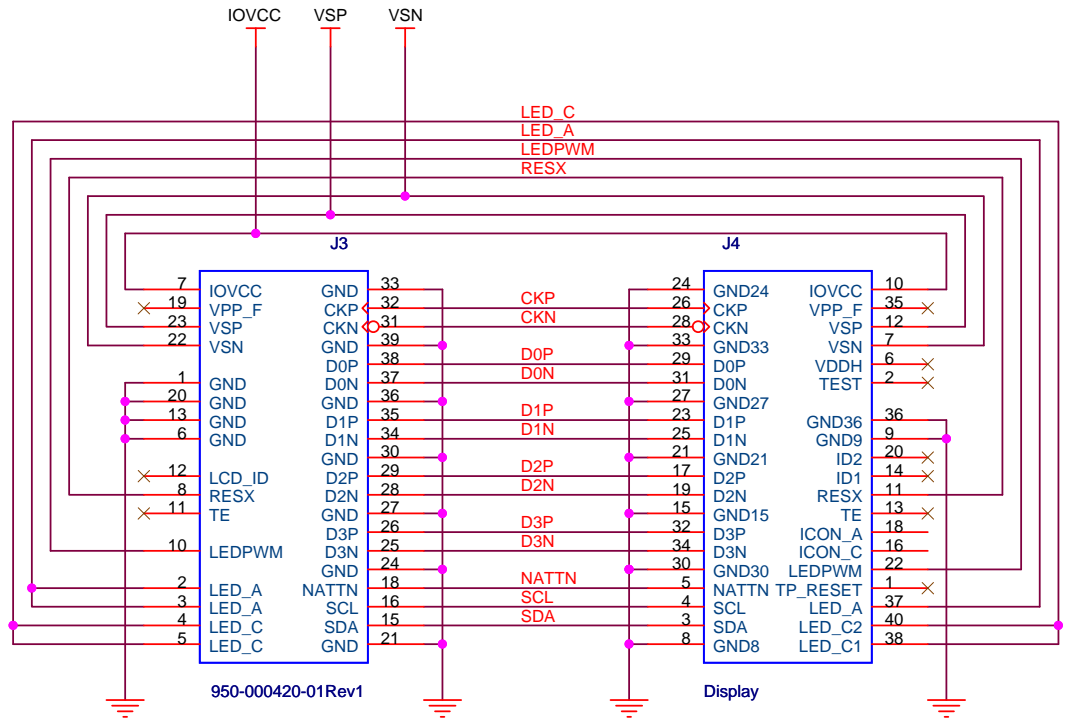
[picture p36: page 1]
NATTN; CKN; CKP; RESX; LEDPWM; LED_A; LED_C; IOVCC; VSP; VSN; Title Title; Title; 950-000420-01Rev1; GND; LED_C 5; SDA; 15 LED_C 4; SCL; 16 LED_A 3; 18 LED_A 2; 36 GND 20; IOVCC 7; GND 13; RESX 8; LEDPWM 10; VSP 23; VSN 22; GND 6; VPP_F 19; GND 1; LCD_ID 12; Display; GND33 33; LED_C1; 38 SDA 3; LED_C2; 40 SCL 4; 37 NATTN 5; TEST; GND27 27; GND36; GND24 24; GND21 21; 12 CKN 28; CKP 26; GND9; GND15 15; GND30 30; VPP_F; TP_RESET; VDDH; ICON_C; 16 ICON_A

SCL
SDA

GND8 8

SCH,Tourmalet Display adaptor

Size Size Size A A A | Document Number Document Number Document Number SC950-000550-01 SC950-000550-01 SC950-000550-01 | Rev Rev Rev 1 1 1

Date: Date: Date: Wednesday, September 06, 2017 Wednesday, September 06, 2017 Wednesday, September 06, 2017 | Sheet Sheet Sheet 1 1 1 of of of 1 1 1
